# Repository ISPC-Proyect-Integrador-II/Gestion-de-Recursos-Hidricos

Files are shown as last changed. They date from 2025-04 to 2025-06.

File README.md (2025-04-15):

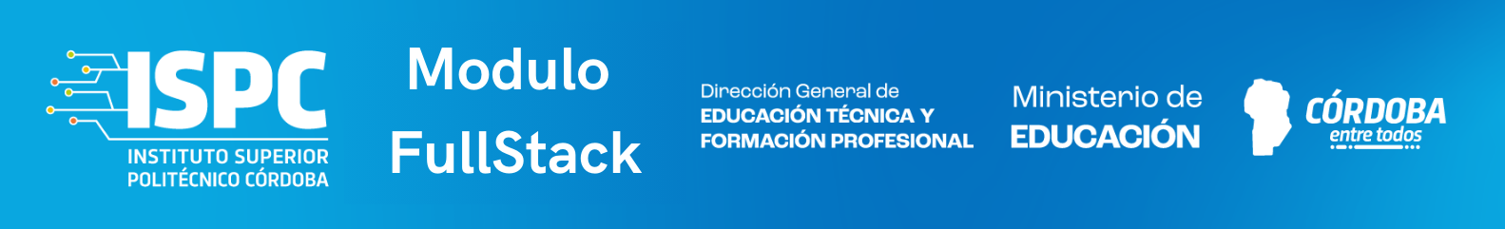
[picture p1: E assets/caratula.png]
Logo de la Institución ISPC


# Módulo Programador FullStack IoT
## Tecnicatura Superior en Telecomunicaciones – Segundo Año

### 🔹 Presentación General  

El módulo Programador FullStack IoT es un espacio interdisciplinario que integra las materias Arquitectura y Conectividad, Sistemas de Control y Servicios y Plataformas, orientado al diseño e implementación de soluciones IoT aplicadas a la industria.
Durante 10 semanas, los estudiantes trabajarán en equipos de 3 a 5 integrantes, desarrollando un proyecto técnico completo que abarque sensado, conectividad, automatización, visualización de datos y documentación profesional.
El trabajo se organiza bajo el enfoque de Aprendizaje Basado en Proyectos (ABP), con metodología Scrum: tres sprints, entregas semanales y seguimiento por parte de los docentes de cada materia. El desarrollo debe gestionarse en GitHub y documentarse en cada etapa.
### 🔹 Selección del Proyecto  

Cada equipo debe elegir un proyecto de base a desarrollar, seleccionando una problemática dentro de una de las siguientes 10 áreas industriales:  

* Gestión Energética

+ Monitoreo Ambiental

+ Trazabilidad de Producción y Logística

+ Mantenimiento Predictivo

+ Seguridad Industrial

+ Monitoreo de Infraestructura

+ Agricultura Inteligente (AgTech)

+ Control de Inventario

+ Gestión de Recursos Hídricos

+ Control de Calidad en Producción

🗂️ Podés acceder a la descripción detallada de cada proyecto en el siguiente enlace:
### 👉 Proyectos para el Módulo PF IoT (PDF) 
🔁 Organización por Sprints
A continuación, se detalla la planificación semanal del módulo, dividida en tres sprints:  

🔁 SPRINT 1  

Exploración y Diseño Conceptual (Semanas 1 a 3)
🎯 Objetivo: Identificar la problemática industrial, investigar, seleccionar tecnologías y diseñar la arquitectura del sistema.
Conformación de equipos y análisis de áreas.

Benchmarking tecnológico y definición del problema.

Selección de sensores, actuadores y protocolos.

Diseño preliminar de red IoT y lógica de control.

Creación del repositorio en GitHub.

Primeros diagramas de arquitectura y flujo.

🔁 SPRINT 2  

Desarrollo e Integración Técnica (Semanas 4 a 7)
🎯 Objetivo: Desarrollar el sistema, integrar sensores, lógica de control y plataforma IoT.
Conexión de sensores físicos o virtuales.

Implementación de lógica de automatización.

Ingesta de datos y visualización inicial en dashboard.

Pruebas funcionales del sistema integrado.

Validación técnica y mejoras sobre el prototipo.

🔁 SPRINT 3  

Optimización y Presentación Final (Semanas 8 a 10)
🎯 Objetivo: Optimizar el sistema, completar la documentación técnica y presentar el proyecto final.
Ajustes técnicos y mejoras visuales.

Finalización de la documentación por materias.

Validación cruzada entre equipos (testing).

Ensayo y presentación final.

Autoevaluación y coevaluación.

### 🎯 Entregable final (Semana 10)  

**Prototipo funcional (simulado o físico)**

**Dashboard operativo**

**Documentación técnica completa**

**Repositorio Git con historial del trabajo**

**Exposición y defensa del proyecto en equipo**

### Profesor
- Cristian Gonzalo Vera | https://github.com/Gona79

### Miembros:
- Luciano Lujan | GitHub: https://github.com/lucianoilujan
- Joaquin Garzón | GitHub: https://github.com/Joacogarzonn
- Durigutti, Vittorio | GitHub: https://github.com/vittoriodurigutti
- Joaquin Zalazar | GitHub: https://github.com/breaakerr
- Lisandro Juncos | GitHub: https://github.com/Lisandro-05
- Nahuel Velez | GitHub: https://github.com/ISPC-TST-PI-I-2024/ISPC_PI_Lucas_Nahuel_Velez 
- Jose Marquez | GitHub: https://github.com/ISPC-TST-PI-I-2024/josemarquez.git
- Maria Lilen Guzmán | GitHub: https://github.com/lilenguzman01
### Índice

### Estructura del Repositorio

- **A requisitos**: Contiene documentos de requisitos proporcionados por el docente.
- **B investigacion**: Investigaciones realizadas por los estudiantes.
- **C prototipo**: Implementaciones específicas de la capa de almacenamiento.
- **D presentacion**: Incluye grabaciones y bitácoras de las reuniones de Scrum, así como las presentaciones de progreso.
- **zassets**: Contiene recursos gráficos como imágenes y otros archivos necesarios para la documentación.

## Stack Tecnológico Común

- Control de Versiones: **Git y GitHub**
- Metodologías Ágiles: **Scrum y Kanban**
- Aprendizaje Basado en Proyectos (ABP)
- Soporte DevOps por parte del docente

## Stack Tecnológico para el Sprint Actual

- IDE: **Visual Studio Code**
- Simulador: **Wokwi o similar**

## Licencia

Este proyecto está licenciado bajo la Licencia Creative Commons Atribución-NoComercial (CC BY-NC). Esta licencia permite que otros remixen, adapten y construyan sobre el trabajo de forma no comercial y, aunque sus nuevos trabajos deben también reconocer al autor original y ser no comerciales, no tienen que licenciar sus obras derivadas en los mismos términos.

Esta licencia es adecuada para un uso educativo y de aprendizaje, permitiendo la libre distribución y utilización del material mientras se protege contra el uso comercial sin autorización previa. Para usos comerciales, es necesario contactar a los autores para obtener permiso.

Para obtener más información sobre esta licencia y ver una copia completa de sus términos, visite [Creative Commons Atribución-NoComercial (CC BY-NC)](https://creativecommons.org/licenses/by-nc/4.0/).

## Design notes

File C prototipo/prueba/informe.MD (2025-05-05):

# Informe Global del Proyecto: Hidroponia Inteligente

El proyecto **Hidroponia Inteligente** está diseñado para monitorear y controlar sistemas hidropónicos usando un ESP32. Su arquitectura modular permite una integración flexible de diversos sensores (temperatura, humedad, pH, nivel de agua, flujo, LDR, gas, INA219) y sistemas de comunicación (WiFi+MQTT, BLE Mesh, LoRa Mesh). Adicionalmente, el sistema incorpora un menú interactivo basado en una pantalla TFT para la selección de opciones y recetas de cultivo, así como un módulo RTC para sincronización de fecha y hora. El sistema admite la operación en modo transmisor o receptor para adaptarse a diferentes arquitecturas de red.

## Características Principales

- **Sensores**: Lectura de información ambiental, de agua, flujo y pH.  
- **Control Automático**: Automatización de riego, iluminación (relé para luces) y alertas basadas en umbrales de seguridad.  
- **Comunicación**:  
  - **WiFi y MQTT**: Conexión remota para enviar y recibir datos.  
  - **BLE Mesh**: Comunicación local entre nodos vía Bluetooth.  
  - **LoRa Mesh**: Comunicación a larga distancia ideal para áreas remotas.
- **RTC**: Módulo de reloj (DS1307/DS3231) para gestionar hora y fecha, permitiendo sincronización y programación de eventos.  
- **Recetas de Cultivo**: Permite guardar y aplicar parámetros óptimos para diferentes cultivos (por ejemplo, lechuga, tomate, albahaca).  
- **Menú Interactivo**: Basado en una pantalla TFT que habilita la navegación entre diferentes opciones: sensores, control, recetas, WiFi, entre otros.  
- **Modos de Operación**:  
  - **Transmisor**: Nodo que recopila y envía datos.  
  - **Receptor**: Nodo que recibe datos y ejecuta acciones basadas en comandos recibidos.

## Arquitectura y Escalabilidad

La estructura modular del código permite realizar ampliaciones y modificaciones sin afectar el funcionamiento global. Cada funcionalidad se encuentra separada en módulos, lo que hace al sistema escalable y de fácil mantenimiento. Además, la integración de múltiples protocolos de comunicación garantiza robustez y adaptabilidad al entorno en que se implemente.

---

# Informe por Carpeta del Proyecto Hidroponia

A continuación, se detalla qué encontrarás en cada carpeta y los archivos asociados, junto con una breve descripción de su función.

## 1. **Raíz del Proyecto**

- **Hidroponia.ino**  
  Archivo principal donde se integran y utilizan todos los módulos. Aquí se define el ciclo de trabajo (setup y loop) que gestiona la inicialización de los distintos módulos, la lectura periódica de sensores, y la gestión de comunicaciones y menús.

- **Configuración.h**  
  Contiene definiciones básicas para la configuración global del sistema (por ejemplo, velocidad de comunicación, versión del firmware, constantes generales).

- **Configuración_avanzada.h**  
  Aquí se establecen parámetros más finos y de calibración, como constantes para calibrar el sensor de pH o la temperatura. Permite ajustar valores sin modificar el código base en otros módulos.

## 2. **src/sensores**

Contiene todo lo relacionado con la lectura y gestión de los sensores.

- **sensores.h / sensores.cpp**  
  Funciones para inicializar y leer datos de varios sensores: DHT11 (temperatura y humedad ambiente), DS18B20 (temperatura del agua), sensor ultrasónico (nivel de agua), caudalímetro (flujo de agua), LDR (luz ambiente), MQ7 (sensor de gas) e INA219 (corriente, voltaje y potencia).

- **ph_sensor.h / ph_sensor.cpp**  
  Código específico para la lectura del sensor de pH. Incluye declaraciones para inicializar el sensor y leer el valor de pH, utilizando una conversión lineal básica que se puede calibrar según las características del sensor.

## 3. **src/control**

Contiene la lógica de control y automatización del sistema.

- **control.h / control.cpp**  
  Módulo que define los umbrales para cada sensor (por ejemplo, rangos de temperatura, humedad, nivel de agua) y gestiona la activación/desactivación de dispositivos (como la bomba de agua) según los datos obtenidos. Incluye funciones para verificar alarmas, automatizar riego y notificar estados.

- **iluminacion.h / iluminacion.cpp**  
  Maneja el control de un relé destinado a la iluminación artificial. Permite inicializar el relé y cambiar su estado (encendido/apagado) para complementar la entrada natural de luz.

## 4. **src/pantalla**

Módulo responsable de la interfaz visual y los menús interactivos.

- **pantalla.h / pantalla.cpp**  
  Código de inicialización y manejo de la pantalla TFT, utilizando la librería Adafruit GFX y ST7735. Se incluyen funciones para animaciones (por ejemplo, modo standby con parpadeo de "ojos") y para actualizar la pantalla según el estado del sistema.

- **menu.h / menu.cpp**  
  Funciones para presentar el Menú Principal. Permite navegar entre las diferentes opciones de configuración del sistema (sensores, control, recetas, WiFi).

- **menu_recetas.h / menu_recetas.cpp**  
  Módulo dedicado al manejo y selección de recetas de cultivo. Permite visualizar y seleccionar recetas predefinidas almacenadas en EEPROM para ajustar parámetros óptimos para diferentes cultivos.

- **menu_wifi.h / menu_wifi.cpp**  
  Proporciona una interfaz para el escaneo y selección de redes WiFi disponibles. Permite al usuario elegir una red y guardar la configuración para conexiones futuras.

## 5. **src/comunicacion**

Contiene todos los módulos relacionados con la comunicación, tanto para la conexión remota como para la comunicación en malla.

- **comunicacion.h / comunicacion.cpp**  
  Módulo central que integra las funciones de comunicación: conexión a WiFi, MQTT, y llamadas a funciones de otros módulos (como BLE y LoRa). Se manejan reconexiones y la publicación de datos (por ejemplo, alertas o datos de sensores).

- **wifi_manager.h / wifi_manager.cpp**  
  Funciones para la gestión del WiFi: escaneo de redes, conexión y almacenamiento de credenciales en EEPROM para que el dispositivo se conecte automáticamente a la red configurada.

- **ble_mesh.h / ble_mesh.cpp**  
  Módulo para la comunicación BLE Mesh. Inicia el servidor BLE, define servicios y características para transmitir y recibir mensajes en la red de malla Bluetooth.

- **lora_mesh.h / lora_mesh.cpp**  
  Módulo para la comunicación LoRa Mesh. Configura el módulo LoRa (por ejemplo, el SX1278) para enviar y recibir mensajes en largas distancias en frecuencias específicas.

- **transmisor.h / transmisor.cpp**  
  Define el modo de operación para el nodo transmisor. Incluye funciones para enviar datos (por ejemplo, en formato JSON) a través de MQTT y otras redes, basándose en la lectura de sensores.

- **receptor.h / receptor.cpp**  
  Define el modo de operación para el nodo receptor. Procesa los mensajes entrantes y ejecuta acciones (por ejemplo, activar la iluminación) según comandos específicos recibidos.

## 6. **src/rtc**

Módulo para el manejo del reloj real (RTC).

- **rtc.h / rtc.cpp**  
  Código para inicializar y sincronizar el RTC (como DS1307 o DS3231). Se incluyen funciones para obtener la fecha y hora actual, y para ajustar el reloj a partir de datos externos (por ejemplo, mediante MQTT).

## 7. **src/recetas**

Módulo para la gestión de recetas de cultivo, que permiten guardar parámetros específicos para diferentes plantas.

- **recetas.h / recetas.cpp**  
  Define una estructura llamada `Receta` que guarda parámetros como temperatura del agua, temperatura ambiente, humedad, nivel de agua, pH e información sobre iluminación. Permite cargar y guardar recetas en la EEPROM, seleccionar una receta y mostrar sus parámetros.

## 8. **bibliotecas**

Esta carpeta contendrá las librerías externas que debes instalar (aunque muchas se descargan automáticamente desde el gestor de librerías de Arduino o PlatformIO). Aquí se pueden incluir, por ejemplo:  
- Adafruit_GFX, Adafruit_ST7735  
- PubSubClient  
- LoRa  
- BLEDevice  
- RTClib  
- EEPROM (ya incluida en Arduino)  

## 9. **Errores y manejo de informacion**

- **errores.h / errores.cpp** 

En la carpeta se encuetra el catagolo de categoria y mensaje por indexacion de los posibles errores en diferentes funciones del sistema, Y la funcion encargada de la gestion y producccion de los mensajes

Se adjunta documento **errores.md** con el catagolo en formato de lectura para facilitar acceso a los posibles errores contemplados
---

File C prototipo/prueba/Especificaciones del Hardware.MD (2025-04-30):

# 🛠️ **Especificaciones del Hardware: Hidroponia Inteligente en ESP32**  

## 📌 **1. Microcontrolador Principal: ESP32**  
El sistema está basado en el **ESP32**, un microcontrolador con conectividad WiFi y Bluetooth, múltiples entradas analógicas/digitales y capacidad de procesamiento eficiente para proyectos IoT y automatización.

### **🔹 Características Clave del ESP32:**  
✔ 240 MHz de frecuencia de CPU.  
✔ 520 KB de SRAM.  
✔ WiFi integrado para conexión remota.  
✔ Bluetooth BLE para comunicación de corto alcance.  
✔ Múltiples puertos ADC y PWM para sensores y actuadores.  
✔ Bajo consumo energético para funcionamiento eficiente.  

### **🔹 Conexión del ESP32:**  
✔ **Alimentación:** Se puede alimentar con **5V desde un adaptador USB** o con una **batería externa**.  
✔ **Pines digitales:** Se usan para controlar el relé de la bomba y la iluminación.  
✔ **Pines analógicos:** Se usan para sensores como pH, flujo y nivel de agua.  

---

## 📌 **2. Sensores Integrados en el Sistema**  

El sistema cuenta con varios sensores para monitoreo en tiempo real:  

### **🔹 Sensor de Temperatura y Humedad (DHT11 / DHT22)**  
✔ Conectado a un **pin digital** del ESP32.  
✔ Mide temperatura y humedad ambiente.  

### **🔹 Sensor de Temperatura del Agua (DS18B20)**  
✔ Conectado mediante **OneWire** a un pin del ESP32.  
✔ Mide la temperatura del agua para optimizar el cultivo.  

### **🔹 Sensor de Nivel de Agua (Ultrasónico HC-SR04)**  
✔ Utiliza **dos pines digitales**: `Trigger` y `Echo`.  
✔ Mide la distancia hasta la superficie del agua.  

### **🔹 Sensor de Flujo de Agua (Caudalímetro YF-S201)**  
✔ Conectado a un **pin de interrupción** del ESP32.  
✔ Mide el flujo de agua en litros por minuto.  

### **🔹 Sensor de pH (Electrodo + Amplificador PH-4502C)**  
✔ Conectado a un **pin analógico** del ESP32.  
✔ Proporciona medición del pH del agua en tiempo real.  

### **🔹 Sensor de Luz (LDR)**  
✔ Conectado a un **pin analógico**.  
✔ Detecta la cantidad de luz ambiental para activar la iluminación artificial.  

### **🔹 Sensor de Gas (MQ7)**  
✔ Conectado a un **pin analógico**.  
✔ Detecta concentraciones de gases que puedan afectar el cultivo.  

### **🔹 Sensor de Corriente y Voltaje (INA219)**  
✔ Conectado vía **I2C** para medir corriente y voltaje en el sistema.  
✔ Permite monitorear el consumo de energía del sistema hidropónico.  

---

## 📌 **3. Actuadores del Sistema**  

El sistema controla dispositivos físicos a través de relés y bombas:  

### **🔹 Relé para la Bomba de Agua**  
✔ Conectado a un **pin digital** del ESP32.  
✔ Activa o desactiva el bombeo según el nivel de agua.  

### **🔹 Relé para la Iluminación Artificial**  
✔ Conectado a un **pin digital** del ESP32.  
✔ Enciende o apaga luces LED para mejorar el crecimiento de las plantas.  

---

## 📌 **4. Módulos de Comunicación**  

### **🔹 Conexión WiFi + MQTT**  
✔ Se configura en `wifi_manager.h` y `comunicacion.h`.  
✔ Permite enviar datos a servidores remotos y recibir comandos.  

### **🔹 BLE Mesh (Bluetooth de corto alcance entre nodos)**  
✔ Configurado en `ble_mesh.h` y `ble_mesh.cpp`.  
✔ Permite comunicación entre múltiples ESP32 sin requerir WiFi.  

### **🔹 LoRa Mesh (Comunicación de larga distancia sin WiFi)**  
✔ Se configura en `lora_mesh.h` y `lora_mesh.cpp`.  
✔ Permite enviar datos a largas distancias en entornos sin Internet.  

---

## 📌 **5. Diagrama de Conexión**  

```
ESP32
 ├── Sensores:
 │   ├── DHT11 (Temp/Humedad) → Pin Digital
 │   ├── DS18B20 (Temp Agua) → Pin OneWire
 │   ├── HC-SR04 (Nivel Agua) → Pines Trigger/Echo
 │   ├── YF-S201 (Flujo Agua) → Pin de interrupción
 │   ├── PH-4502C (Sensor pH) → Pin Analógico
 │   ├── LDR (Sensor de Luz) → Pin Analógico
 │   ├── MQ7 (Sensor de Gas) → Pin Analógico
 │   ├── INA219 (Corriente/Voltaje) → I2C
 ├── Actuadores:
 │   ├── Relé Bomba Agua → Pin Digital
 │   ├── Relé Iluminación → Pin Digital
 ├── Comunicación:
 │   ├── WiFi (MQTT) → `wifi_manager.h`
 │   ├── BLE Mesh → `ble_mesh.h`
 │   ├── LoRa Mesh → `lora_mesh.h`
```

---

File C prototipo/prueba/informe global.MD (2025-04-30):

# Informe Global del Proyecto: Hidroponia Inteligente para ESP32

El proyecto **Hidroponia Inteligente** está desarrollado sobre un ESP32 y está orientado a monitorear y controlar un sistema hidropónico de forma remota e inteligente. La arquitectura es modular, lo que permite integrar múltiples sensores, gestionar la automatización y establecer comunicación de diversas formas (WiFi + MQTT, BLE Mesh y LoRa Mesh).

## Características Principales

- **Sensores y Medidas**  
  - *Sensores ambientales*: Temperatura y humedad (DHT11).  
  - *Sensor de agua*: Temperatura (DS18B20), nivel (ultrasónico) y flujo (caudalímetro).  
  - *Medición adicional*: Sensor de pH (con conversión básica que se puede calibrar).  
  - *Otros*: Sensor de luz (LDR), sensor de gas (MQ7) y monitorización de corriente/voltaje (INA219).

- **Control y Automatización**  
  - Gestión de riego y control de bomba.
  - Control de iluminación artificial mediante un relé.
  - Verificación de alarmas y notificaciones vía MQTT.
  - Automatización adaptativa a partir de umbrales configurables (definidos en el módulo de control).

- **Comunicaciones y Redes**  
  - **WiFi y MQTT:** El ESP32 se conecta a una red WiFi y publica datos en un broker MQTT.  
  - **BLE Mesh:** Operación en red de malla a corto alcance mediante BLE.  
  - **LoRa Mesh:** Comunicación a largas distancias en redes remotas.  
  - **Modos de Operación:** Se puede configurar el nodo en modo transmisor (envía datos) o receptor (procesa y ejecuta comandos recibidos).

- **Interfaz Visual y Menús**  
  - Uso de una pantalla TFT (con Adafruit_GFX y ST7735) para mostrar información, menús interactivos y animaciones (modo standby, alertas, etc.).  
  - Menús para la configuración general, selección de recetas de cultivo y de red WiFi.

- **Recetas de Cultivo y Configuración**  
  - Almacenamiento en EEPROM de recetas con parámetros óptimos para diferentes cultivos (p.ej. lechuga, tomate, albahaca).  
  - Parámetros ajustables y calibración fina a través de archivos de configuración.

- **Sincronización Horaria (RTC)**  
  - Integración de módulos RTC (DS1307/DS3231) para mantener la hora correcta, programar eventos y registrar datos con marca temporal.

## Ventajas y Escalabilidad

- **Modularidad:** Cada funcionalidad se encuentra en su propio módulo, lo que facilita la ampliación o modificación sin afectar el sistema global.
- **Flexibilidad:** Los nodos se pueden configurar como transmisores o receptores, permitiendo distintas arquitecturas de red para distribuir las tareas.
- **Robustez:** Los diferentes canales de comunicación (WiFi, BLE, LoRa) y el almacenamiento local (EEPROM) garantizan persistencia y adaptabilidad a diversas condiciones de red y energía.
- **Diseñado para ESP32:** Aprovecha la capacidad de procesamiento, conectividad WiFi/BLE y las múltiples interfaces analógicas/digitales que posee este microcontrolador.

---

# Informe por Carpeta del Proyecto

A continuación se describe en detalle la estructura del proyecto y los archivos que encontrarás en cada carpeta, junto con una breve descripción de sus responsabilidades.

## Raíz del Proyecto

- **Hidroponia.ino**  
  Es el archivo principal que integra todos los módulos. En él se define el ciclo de trabajo (`setup()` y `loop()`), donde se inicializan la pantalla, sensores, control, comunicaciones y menús, y se coordina la lectura y envío de datos periódicamente.

- **Configuración.h**  
  Contiene definiciones y constantes globales (p.ej. velocidad de comunicación, versión del firmware) que se usan en varias partes del proyecto.

- **Configuración_avanzada.h**  
  Se establecen parámetros finos de calibración y ajustes avanzados (por ejemplo, constantes de calibración para el sensor de pH o parámetros de referencia para otros sensores).

## Carpeta `src/sensores`

- **sensores.h / sensores.cpp**  
  Funcionalidad común para la lectura y manejo de sensores:
  - Inicializa y lee datos de DHT11, DS18B20, sensor ultrasónico, caudalímetro, LDR, MQ7 y INA219.
  - Proporciona variables globales para almacenar los valores medidos (temperatura del agua, temperatura ambiente, nivel de agua, flujo, etc.).

- **ph_sensor.h / ph_sensor.cpp**  
  Específico para el sensor de pH:
  - Se encarga de inicializar el sensor y realizar la conversión analógica a un valor de pH, utilizando una fórmula básica que puede ser ajustada posteriormente.

## Carpeta `src/control`

- **control.h / control.cpp**  
  Define la lógica de control:
  - Establece umbrales para activar la bomba, gestionar riego y otros dispositivos.
  - Incluye funciones para verificar alarmas basadas en las lecturas de los sensores y notificar eventos especiales (por ejemplo, baja del nivel de agua o pH fuera de rango).

- **iluminacion.h / iluminacion.cpp**  
  Maneja el control de un relé destinado a la iluminación artificial:
  - Se definen funciones para inicializar el relé y cambiar su estado (encendido/apagado) dependiendo de las condiciones ambientales o configuraciones manuales.

## Carpeta `src/pantalla`

- **pantalla.h / pantalla.cpp**  
  Encargado de la interfaz visual:
  - Inicializa la pantalla TFT y define funciones para actualizarla, mostrar animaciones (modo standby o alertas) y renderizar información en pantalla.

- **menu.h / menu.cpp**  
  Proporciona el menú principal del sistema:
  - Maneja la navegación del usuario para acceder a distintos apartados (sensores, control, recetas y configuración WiFi).
  
- **menu_recetas.h / menu_recetas.cpp**  
  Gestión del menú de recetas de cultivo:
  - Permite la visualización, selección y edición de recetas almacenadas en EEPROM para ajustar parámetros de cultivo.
  
- **menu_wifi.h / menu_wifi.cpp**  
  Funcionalidades para la selección de red WiFi:
  - Escanea las redes disponibles, muestra una lista en la pantalla y permite al usuario seleccionar la red a la que conectar el ESP32.

## Carpeta `src/comunicacion`

- **comunicacion.h / comunicacion.cpp**  
  Módulo central para la gestión de comunicaciones:
  - Integra funciones para conectarse a WiFi, a un broker MQTT y para manejar la publicación y suscripción de mensajes.
  
- **wifi_manager.h / wifi_manager.cpp**  
  Gestión de las conexiones WiFi:
  - Escanea redes WiFi, conecta al canal seleccionado y guarda los datos en EEPROM para la reconexión automática.
  
- **ble_mesh.h / ble_mesh.cpp**  
  Módulo para la comunicación mediante BLE Mesh:
  - Configura un servidor BLE en el ESP32, define servicios y características para transmitir mensajes por Bluetooth en una red de malla.
  
- **lora_mesh.h / lora_mesh.cpp**  
  Módulo para la comunicación a larga distancia vía LoRa:
  - Configura el módulo LoRa (por ejemplo, SX1278) con los pines y frecuencia adecuados, y gestiona el envío y recepción de mensajes.
  
- **transmisor.h / transmisor.cpp**  
  Define el modo transmisor:
  - Recopila datos de los sensores y los envía (por ejemplo, vía MQTT). Se habilita o deshabilita mediante una variable (esNodoTransmisor).
  
- **receptor.h / receptor.cpp**  
  Define el modo receptor:
  - Procesa los mensajes recibidos (por ejemplo, comandos para activar iluminación o ajustar parámetros) y ejecuta acciones en consecuencia.

## Carpeta `src/rtc`

- **rtc.h / rtc.cpp**  
  Módulo para la gestión del reloj real (RTC):
  - Inicializa el RTC, obtiene la fecha y hora actual y permite sincronizar el reloj (por ejemplo, mediante mensajes recibidos por MQTT).

## Carpeta `src/recetas`

- **recetas.h / recetas.cpp**  
  Gestión de recetas de cultivo:
  - Define la estructura `Receta` que almacena parámetros como temperatura, humedad, nivel de agua, pH e iluminación.
  - Permite cargar y guardar estas recetas en EEPROM, seleccionar una receta y mostrar sus parámetros en el sistema.

## Carpeta `bibliotecas`

- **Librerías Externas**  
  Esta carpeta se utiliza para almacenar (o referenciar) las librerías externas requeridas, tales como:
  - Adafruit_GFX, Adafruit_ST7735 (para la pantalla TFT).  
  - PubSubClient (para MQTT).  
  - LoRa, BLEDevice, RTClib y EEPROM (incluida en Arduino).  
  La mayoría de estas librerías se instalan a través del gestor de librerías de Arduino o PlatformIO.

---

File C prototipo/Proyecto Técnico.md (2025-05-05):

# 🌱 Sistema Hidropónico Automatizado con ESP32

## 🧠 Microcontrolador
- **Placa principal:** NodeMCU ESP32 WROOM (38 pines)
- **Tensión de operación:** 3.3V
- **Tensión de alimentación:** 5V vía USB
- **Comunicación:** Wi-Fi, Bluetooth, UART, SPI, I2C

## 📌 Mapeo Completo de Pines ESP32 (NodeMCU ESP32 WROOM)

| Pin | GPIO | Nombre | Estado | Uso en Proyecto |
|-----|---|---|---|---|
| 1 | - | 3V3 | Ocupado | Alimentación para sensores de 3.3V |
| 2 | GPIO23 | IO23 | Ocupado | LoRa MOSI |
| 3 | GPIO22 | IO22/SCL | Ocupado | I2C SCL (INA219, RTC DS1307) |
| 4 | GPIO1 | TX | Libre | - |
| 5 | GPIO3 | RX | Libre | - |
| 6 | GPIO21 | IO21/SDA | Ocupado | I2C SDA (INA219, RTC DS1307) |
| 7 | GND | GND | Ocupado | Tierra común |
| 8 | GPIO19 | IO19 | Ocupado | LoRa MISO |
| 9 | GPIO18 | IO18 | Ocupado | LoRa SCK |
| 10 | GPIO5 | IO5 | Ocupado | LoRa NSS |
| 11 | GPIO17 | IO17 | Ocupado | SIM800L TX |
| 12 | GPIO16 | IO16 | Ocupado | SIM800L RX |
| 13 | GPIO4 | IO4 | Libre | - |
| 14 | GPIO0 | IO0 | Ocupado | Display TFT RESET |
| 15 | GPIO2 | IO2 | Libre | - |
| 16 | GPIO15 | IO15 | Ocupado | LoRa RST |
| 17 | GPIO13 | IO13 | Ocupado | Display TFT CS |
| 18 | GPIO12 | IO12 | Ocupado | Display TFT DC, HC-SR04 TRIG |
| 19 | GPIO14 | IO14 | Ocupado | Display TFT MOSI |
| 20 | GPIO27 | IO27 | Ocupado | Display TFT SCK, Buzzer Pasivo |
| 21 | GPIO26 | IO26 | Ocupado | Bomba Sumergible (Relay 1 Canal) |
| 22 | GPIO25 | IO25 | Ocupado | DHT11/DHT22 DATA |
| 23 | GPIO33 | IO33 | Ocupado | DS18B20 DATA |
| 24 | GPIO32 | IO32 | Ocupado | HC-SR04 ECHO |
| 25 | GPIO35 | IO35 | Ocupado | Relay 2 Canal |
| 26 | GPIO34 | IO34 | Ocupado | LoRa DIO0 |
| 27 | GPIO39 | IO39/VN | Ocupado | Sensor LDR, Medidor de pH |
| 28 | GPIO36 | IO36/VP | Ocupado | Sensor MQ-7 |
| 29 | EN | EN | Sistema | - |
| 30 | - | 5V | Ocupado | Alimentación para sensores de 5V |

## 📌 Distribución de Pines para Sensores

| Sensor / Módulo | Tipo de conexión | Pines ESP32 |
|---|---|---|
| **Bomba Sumergible (Relay)** | Digital | GPIO 26 |
| **Buzzer Pasivo** | PWM / Digital | GPIO 27 |
| **Caudalímetro** | Pulso digital | GPIO 32 |
| **Sensor de Corriente INA219** | I2C | SDA = GPIO 21, SCL = GPIO 22 |
| **RTC DS1307 + EEPROM AT24C32** | I2C | SDA = GPIO 21, SCL = GPIO 22 |
| **Sensor de Temperatura DS18B20** | 1-Wire | GPIO 33 |
| **Sensor de Gas MQ7** | Analógico | GPIO 36 (VP) |
| **Display TFT ST7735 (SPI)** | SPI | CS = GPIO 13, DC = GPIO 12, RESET = GPIO 0, MOSI = GPIO 14, SCK = GPIO 27 |
| **Sensor DHT11/DHT22** | Digital | GPIO 25 |
| **Sensor de Luz LDR** | Analógico | GPIO 39 (VN) |
| **Sensor Ultrasonido HC-SR04** | Digital | TRIG = GPIO 12, ECHO = GPIO 32 |
| **Módulo GSM SIM800L** | UART | RX = GPIO 16, TX = GPIO 17 |
| **Módulo LoRa SX1278 (SPI)** | SPI | NSS = GPIO 5, MOSI = GPIO 23, MISO = GPIO 19, SCK = GPIO 18, RST = GPIO 15, DIO0 = GPIO 34 |
| **Relay 1 Canal** | Digital | GPIO 26 |
| **Relay 2 Canal** | Digital | GPIO 35 |
| **Medidor de pH** | ADC | GPIO 39 (ADC1_CH3) |

## 🔌 Conexiones de Módulos y Sensores

### 1. **Bomba Sumergible + Relay**
- **Relay VCC** → 5V
- **Relay GND** → GND
- **Relay IN** → GPIO 26
- **COM (Relay)** → + de la bomba
- **NO (Relay)** → + de fuente de 5V externa
- **Bomba GND** → GND fuente

---

### 2. **Buzzer Pasivo**
- **VCC** → 5V
- **GND** → GND
- **Señal** → GPIO 27

---

### 3. **Caudalímetro**
- **VCC** → 5V
- **GND** → GND
- **Señal (pulso)** → GPIO 32

---

### 4. **Sensor de Corriente INA219**
- **VCC** → 3.3V
- **GND** → GND
- **SDA** → GPIO 21
- **SCL** → GPIO 22

---

### 5. **RTC DS1307 + EEPROM**
- **VCC** → 3.3V o 5V
- **GND** → GND
- **SDA** → GPIO 21
- **SCL** → GPIO 22

---

### 6. **Sensor DS18B20**
- **VCC** → 3.3V
- **GND** → GND
- **DATA** → GPIO 33
- **Resistencia** (pull-up 4.7kΩ entre DATA y VCC)

---

### 7. **Sensor MQ-7 (CO)**
- **VCC** → 5V
- **GND** → GND
- **AOUT** → GPIO 36

---

### 8. **Display TFT ST7735**
- **VCC** → 3.3V
- **GND** → GND
- **CS** → GPIO 13
- **RESET** → GPIO 0
- **DC** → GPIO 12
- **MOSI** → GPIO 14
- **SCK** → GPIO 27

---

### 9. **Sensor DHT11/DHT22**
- **VCC** → 3.3V
- **GND** → GND
- **DATA** → GPIO 25

---

### 10. **Sensor de Luz (LDR)**
- Un extremo del **LDR** → 3.3V
- Otro extremo → resistencia de 10kΩ a GND y punto medio al GPIO 39

---

### 11. **HC-SR04**
- **VCC** → 5V
- **GND** → GND
- **TRIG** → GPIO 12
- **ECHO** → GPIO 32 *(usar divisor de voltaje para 3.3V)*

---

### 12. **SIM800L (Módulo GSM)**
- **VCC** → Fuente externa 4V
- **GND** → GND común
- **TX (SIM800L)** → GPIO 16 (RX ESP32)
- **RX (SIM800L)** → GPIO 17 (TX ESP32) *(usar 3.3V)*

---

### 13. **LoRa SX1278**
- **VCC** → 3.3V
- **GND** → GND
- **MOSI** → GPIO 23
- **MISO** → GPIO 19
- **SCK** → GPIO 18
- **NSS (CS)** → GPIO 5
- **RESET** → GPIO 15
- **DIO0** → GPIO 34

---

### 14. **Medidor de pH**
- **VCC** → 5V
- **GND** → GND
- **Salida Analógica** → GPIO 39 *(ADC1_CH3)*

---

## 📋 Lista de Materiales

| Componente | Cantidad | Descripción |
|---|---|---|
| NodeMCU ESP32 WROOM | 1 | Microcontrolador con WiFi y Bluetooth (38 pines) |
| Relay 1 Canal | 1 | Para control de bomba sumergible |
| Relay 2 Canal | 1 | Para control de actuadores adicionales |
| Buzzer Pasivo | 1 | Para alertas sonoras |
| Caudalímetro | 1 | Sensor de flujo de agua (0.3-6 L/min) |
| INA219 | 1 | Sensor de corriente de alta precisión |
| DS1307 + AT24C32 | 1 | Reloj de tiempo real con EEPROM |
| DS18B20 | 1 | Sensor de temperatura resistente al agua |
| MQ-7 | 1 | Sensor de monóxido de carbono |
| Display TFT ST7735 | 1 | Pantalla a color SPI 1.8" |
| DHT11/DHT22 | 1 | Sensor de temperatura y humedad |
| LDR | 1 | Fotorresistor para medir intensidad de luz |
| HC-SR04 | 1 | Sensor ultrasónico de distancia |
| SIM800L | 1 | Módulo GSM para comunicación celular |
| LoRa SX1278 | 1 | Módulo de comunicación de largo alcance |
| Sensor de pH | 1 | Medidor del pH del agua |
| Bomba Sumergible | 1 | Bomba de agua para circulación |
| Resistencias | Varias | 10kΩ (para LDR), 4.7kΩ (para DS18B20), divisor de voltaje |
| Cables Dupont | Varios | Para interconexión de componentes |
| Protoboard | 1 | Para montaje de circuito |
| Fuente de alimentación | 1 | 5V/2A para ESP32 y 4V para SIM800L |

## 🔄 Tipos de Conexiones

### I2C (Inter-Integrated Circuit) – Bus compartido
Todos los módulos que usan I2C están en el mismo bus para reducir consumo y mejorar estabilidad:
| Sensor / Módulo | Dirección I2C | Pines ESP32 |
|---|---|---|
| Sensor de Corriente INA219 | 0x40 | SDA = GPIO 21, SCL = GPIO 22 |
| RTC DS1307 + EEPROM AT24C32 | 0x68 / 0x57 | SDA = GPIO 21, SCL = GPIO 22 |

### SPI (Serial Peripheral Interface) – Bus compartido
Para mejorar eficiencia, algunos dispositivos comparten el bus SPI con pines CS independientes:
| Sensor / Módulo | Pines ESP32 |
|---|---|
| Display TFT ST7735 | MOSI = GPIO 14, SCK = GPIO 27, CS = GPIO 13 |
| Módulo LoRa SX1278 | MOSI = GPIO 23, MISO = GPIO 19, SCK = GPIO 18, CS = GPIO 5 |

### Entradas Analógicas
El ESP32 cuenta con ADC (convertidor analógico a digital) en varios pines:
| Sensor / Módulo | Canal ADC | Pines ESP32 |
|---|---|---|
| Sensor LDR | ADC1_CH3 | GPIO 39 (VN) |
| Sensor MQ-7 | ADC1_CH0 | GPIO 36 (VP) |
| Medidor de pH | ADC1_CH3 | GPIO 39 (VN) |

## ⚙️ Funcionalidades del Sistema
✅ Control automático de riego con bomba sumergible  
✅ Medición de caudal con sensor de flujo  
✅ Monitoreo de temperatura ambiental y del agua  
✅ Medición de concentración de CO2  
✅ Visualización en pantalla TFT  
✅ Envío de alertas por SMS vía GSM (SIM800L)  
✅ Sincronización horaria con RTC DS1307  
✅ Nivel de tanque por ultrasonido  
✅ Comunicación remota por radiofrecuencia (LoRa)  
✅ Detección de condiciones de luz (cultivo LED o solar)  
✅ Medición de pH del agua

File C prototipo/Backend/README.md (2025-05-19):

## API 01

### Procesamiento de Informacion y Registro en BD

Esta API funcionara como el nodo conector entre el dispositivo fisico y las Bases de datos
Purgara la informacion, y ordenara, y posteriormente registrara en los formatos adecuador para poder reflejar los datos de manera informativa, y en tiempo real. 
La misma escuchara de forma pasiva los mensajes presnetes en los topicos en que los dispositivos registren sus lecturas, corriendo en un contenedor Docker, conectado a la red donde se desplegaran asi mismo la base de datos en MySQL e InfluxDB.

---

### Estructura del Directorio

- 📦Backend
-  ┣ 📂app                          // Directorio principal de la aplicacion
-  ┃ ┣ 📂api                        // Elementos de inico de la AIP y gestion de routas [host/api]
-  ┃ ┃ ┣ 📜routes.py                // Gestor de rutas definidas en la aplicacion
-  ┃ ┃ ┗ 📜__init__.py              // Elemento importador de los endpoind del directorio 
-  ┃ ┣ 📂models                     // Elementos asociado a modelos predefinidos, de momento solo estructura de los mensajes recividos
-  ┃ ┃ ┗ 📜mensaje.py               // Estructurador de formato de los mensjaes
-  ┃ ┣ 📂services                   // Estructura la conexion con los diferentes servicios a los que conecta la API
-  ┃ ┃ ┣ 📜influx_serv.py           // Estructura conexion con la base de datos en Influx
-  ┃ ┃ ┗ 📜mysql_serv.py            // Estructura conexion con la base de datos en MySQL
-  ┃ ┣ 📂utils
-  ┃ ┃ ┗ 📜logger.py                // Gestiona los logs del sistema, asi como la categorizacion de los mismos
-  ┃ ┣ 📜config.py                  // Configuracion de la aplicacion y sus endpoints. Estps son llamados del .env
-  ┃ ┣ 📜main.py                    // Cuerpo de la aplicacion. Inicio, gestion del listener, del healtcheck, y ruta principal  
-  ┃ ┣ 📜mqtt_listener.py           // Listener en segundo plano de las conexiones y topicos MQTT
-  ┃ ┗ 📜__init__.py
-  ┣ 📜.env                         // Documento de enviroment donde se definen los valores finales antes de desplegar
-  ┣ 📜.gitignore                   
-  ┣ 📜docker-compose.yml           // Docke-compose para creacion y parametros del contenedor
-  ┣ 📜Dockerfile
-  ┣ 📜README.md
-  ┗ 📜requirements.txt             // Librerias/instalaciones que deben ejecutarse en la imagen del contenedor

---

### Instacion solicitadas en el "requirements.txt"
- fastapi
    - Framework web asíncrono sobre el que montamos nuestros endpoints y el ciclo de vida de la app.
- uvicorn[standard]
    - Servidor ASGI ligero para ejecutar FastAPI, con extras ([standard]) como watchdog para recarga en caliente.
- paho-mqtt
    - Cliente MQTT para suscribirte a topics y procesar mensajes.
- mysql-connector-python
    - Driver oficial de Oracle para conectar a MySQL desde Python.
- influxdb-client
    - Cliente oficial para lectura/escritura en InfluxDB 2.x.
- python-dotenv
    - (Opcional si tu editor o entorno no carga .env automáticamente) permite que Pydantic BaseSettings lea tu .env.
- sqlalchemy
    - ORM/kit de conexión SQL que te facilitará abstraer consultas y gestión de sesiones en MySQL.

---

### Flujo de Datos

```mermaid
flowchart LR
  %% Dispositivo que envía mensajes al broker MQTT
  Dispositivo[Dispositivo]

  %% MQTT subsystem
  subgraph MQTT_Listener
    direction TB
    Broker[MQTT Broker]
    Listener["MQTTListener
(on_message)"]
  end

  %% Persistence services
  subgraph Persistence
    direction TB
    MySQLService[MySQL Service]
    InfluxService[InfluxDB Service]
    MySQLDB[(MySQL DB)]
    InfluxDB[(InfluxDB)]
  end

  %% HTTP API
  subgraph HTTP_API
    direction TB
    Client["API Client
(e.g. dashboard)"]
    FastAPI[FastAPI App]
    Router[/api router/]
    Health[/GET /health/]
    Topics[/GET /api/topics/]
    Messages[/GET /api/messages/]
  end

  %% Connections
  Dispositivo --> Broker
  Broker --> Listener
  Listener -->|payload JSON| MySQLService
  Listener -->|payload JSON| InfluxService
  MySQLService --> MySQLDB
  InfluxService --> InfluxDB

  Client --> FastAPI
  FastAPI --> Health
  FastAPI --> Router
  Router --> Topics
  Router --> Messages
  Messages -->|consulta| MySQLService
  Messages -->|consulta| InfluxService

```

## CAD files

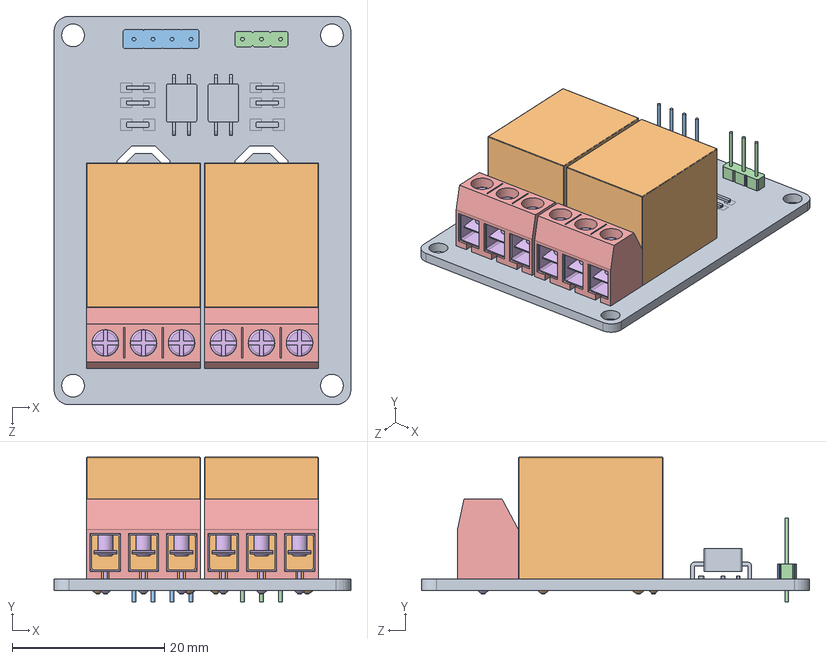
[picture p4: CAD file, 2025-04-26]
C prototipo/Extructura 3D/Archivos editables/Relay - 2 Channel - 2PH63091A - Montaj.SLDASM
39.0 x 19.0 x 51.0 mm
2PH63091A Board
Relay Body x 2
4 Headers
Headers
Clamp Body x 2
Metal Clamp Part x 6

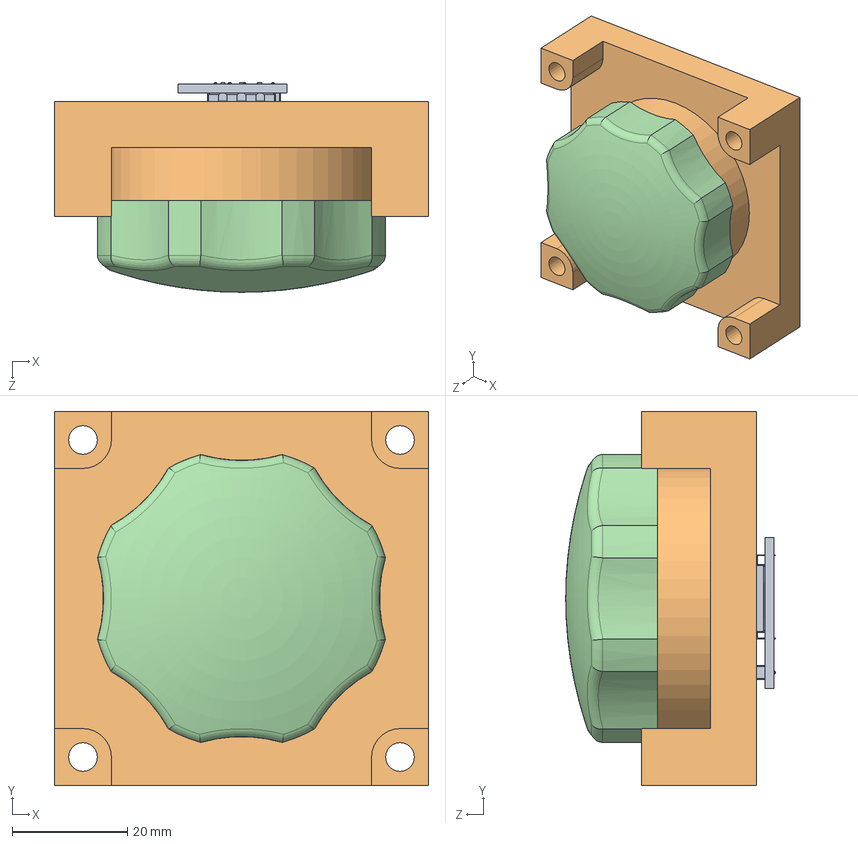
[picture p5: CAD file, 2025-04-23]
C prototipo/Extructura 3D/Archivos editables/perilla.SLDASM
65.0 x 65.0 x 36.4 mm
Rotary Encoder - KY-040
chasis_perilla
rodamiento
perilla52

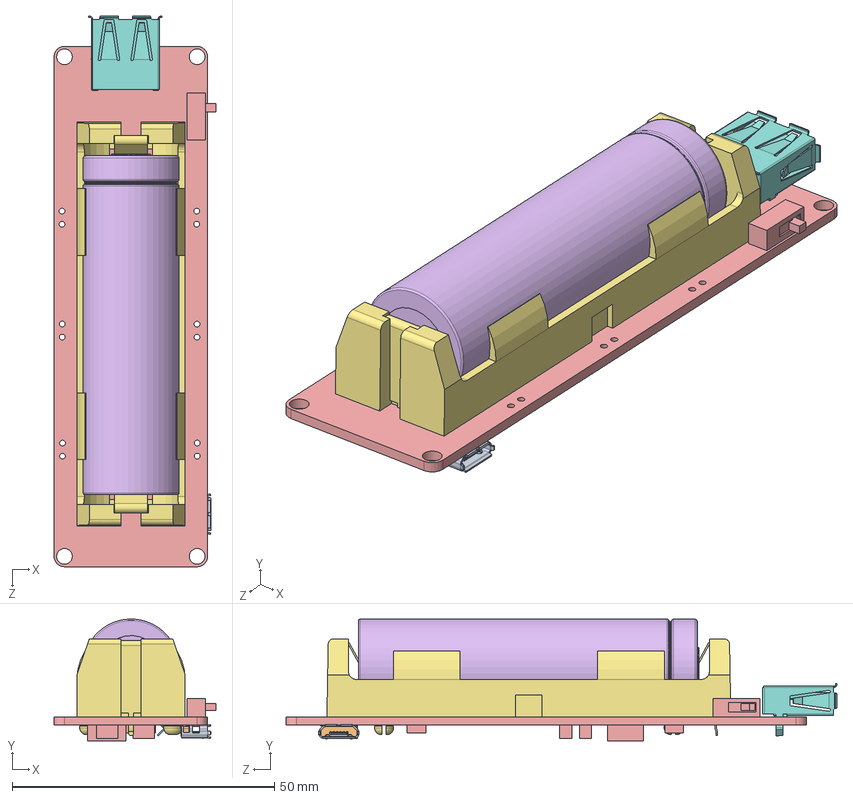
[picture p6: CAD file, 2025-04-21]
C prototipo/Extructura 3D/Archivos editables/Wemos Battery Shield V3.SLDASM
30.9 x 23.2 x 105.0 mm
shield.step
socket_housing.step
socket_plate.step
terminal.step x 5
Placa.step
PANASONIC_NCR-18650B.step
Battery Holder.step
Female USB.step

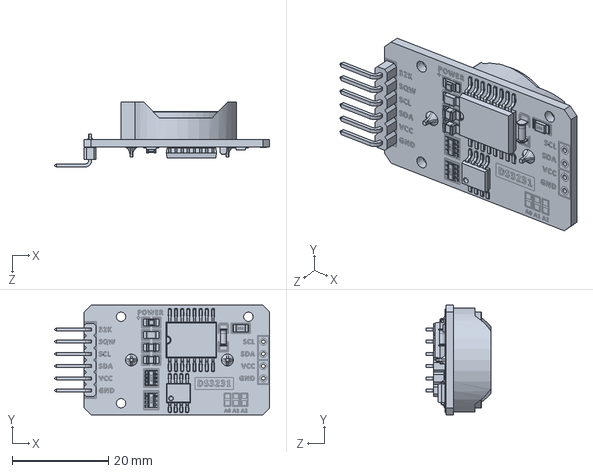
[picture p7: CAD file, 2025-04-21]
C prototipo/Extructura 3D/Archivos editables/DS3231 RTC.SLDASM
44.8 x 22.8 x 13.5 mm

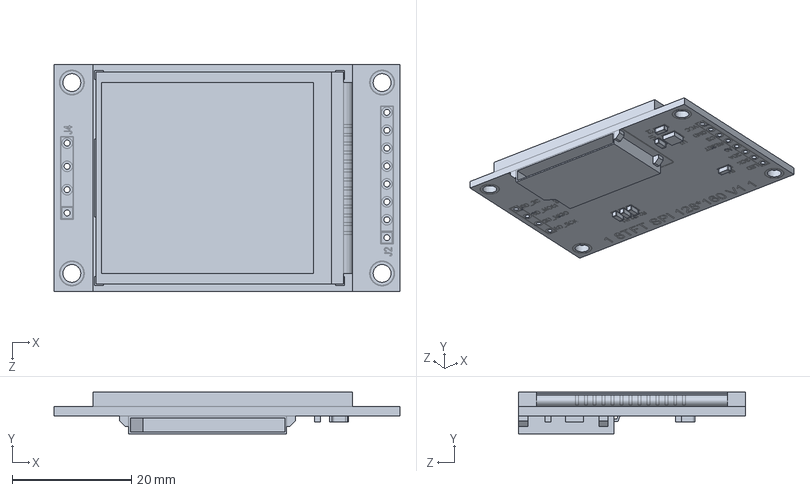
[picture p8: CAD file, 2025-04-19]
C prototipo/Extructura 3D/Archivos editables/LCD_TFT_1.8_SPI_ST7735.SLDASM
58.0 x 7.00 x 38.0 mm

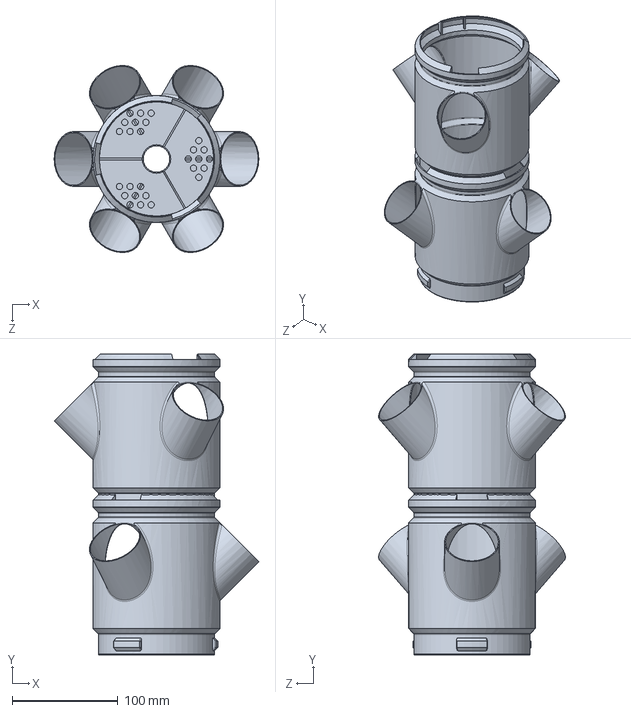
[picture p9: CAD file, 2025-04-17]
C prototipo/Extructura 3D/Archivos editables/Assem1.SLDASM
193.5 x 284.5 x 176.9 mm
cup_holder_fer x 2

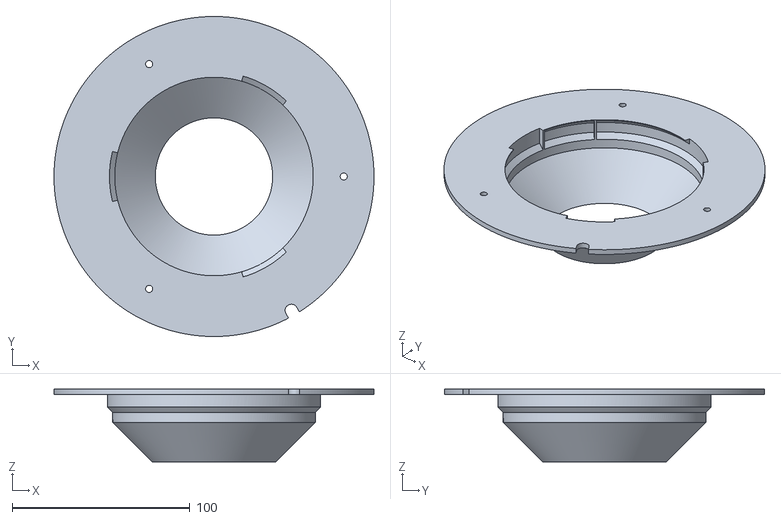
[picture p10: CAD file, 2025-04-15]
C prototipo/Extructura 3D/Adaptador.stl
180.0 x 180.0 x 41.0

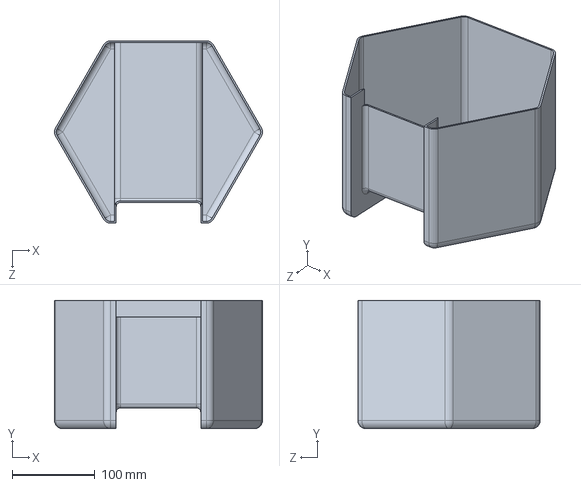
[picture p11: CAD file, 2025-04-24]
C prototipo/Extructura 3D/version 1_1/base 1_1.SLDPRT
250.9 x 155.0 x 220.0 mm

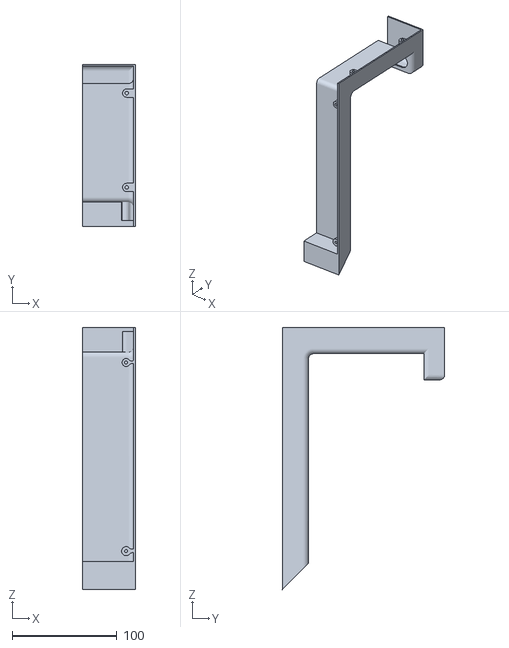
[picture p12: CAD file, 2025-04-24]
C prototipo/Extructura 3D/version 1_1/Impresiones/STL/box-control_I.STL
50.1 x 155.0 x 250.0

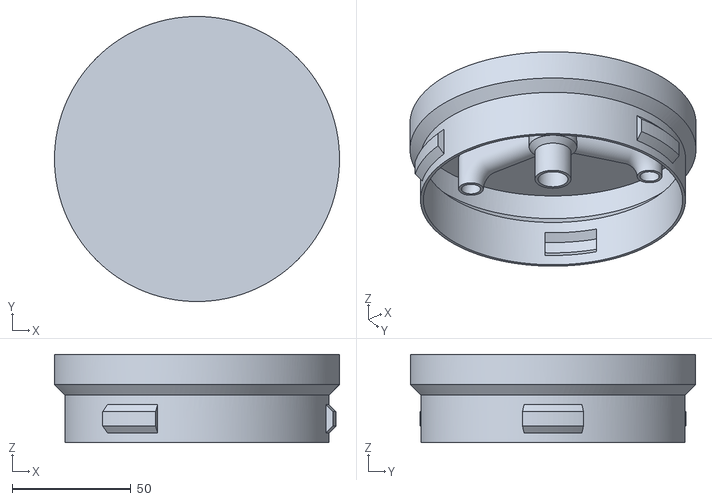
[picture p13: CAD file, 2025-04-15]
C prototipo/Extructura 3D/tapa.stl
120.0 x 120.0 x 37.1

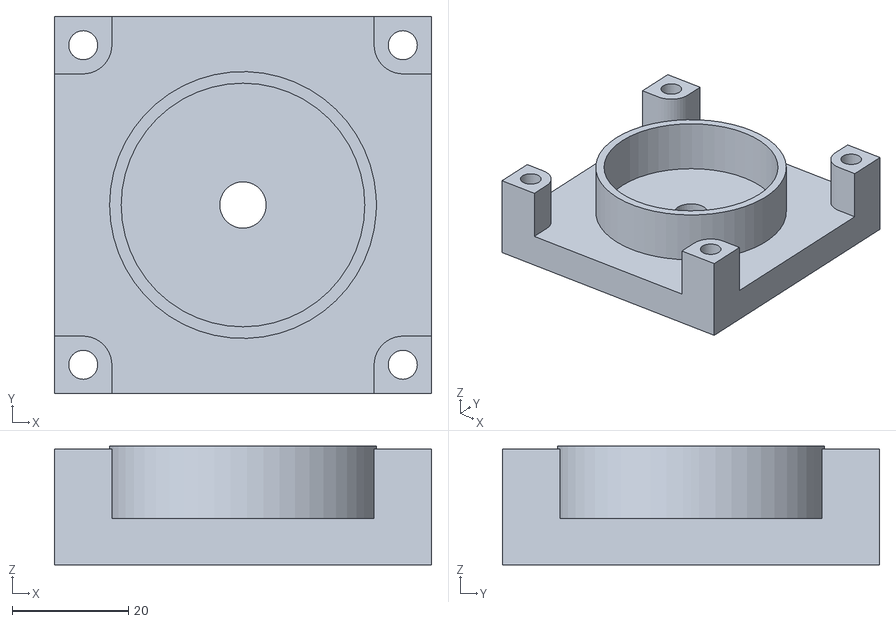
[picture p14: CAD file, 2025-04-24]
C prototipo/Extructura 3D/version 1_1/Impresiones/STL/chasis_perilla.STL
65.0 x 65.0 x 20.5

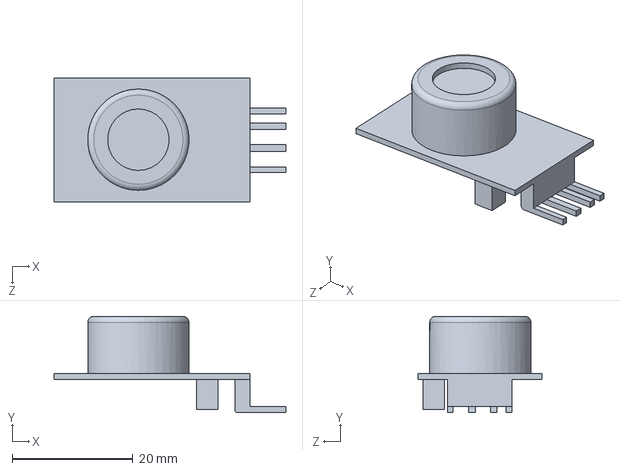
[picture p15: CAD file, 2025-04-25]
C prototipo/Extructura 3D/Archivos editables/MQ-7.SLDPRT
38.5 x 16.0 x 20.5 mm

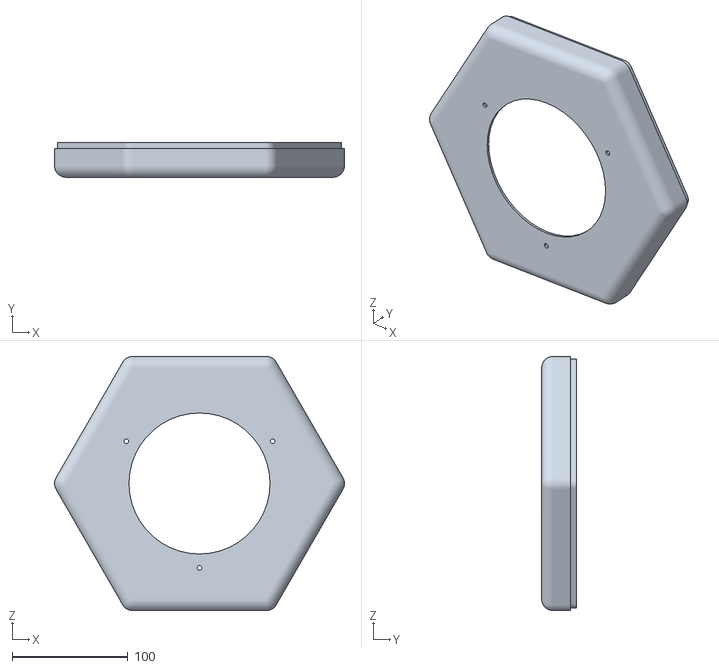
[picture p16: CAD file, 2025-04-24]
C prototipo/Extructura 3D/version 1_1/Impresiones/STL/techo_tanque.STL
250.9 x 30.0 x 220.0

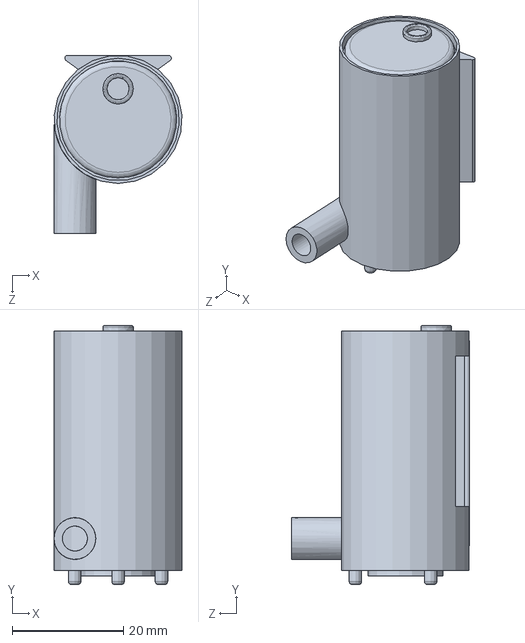
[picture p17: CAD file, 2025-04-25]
C prototipo/Extructura 3D/Archivos editables/mini_pump.SLDPRT
23.0 x 46.5 x 32.0 mm

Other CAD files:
C prototipo/Extructura 3D/Archivos editables/HC-SR04.sldasm
C prototipo/Extructura 3D/version 1_1/box-control_D.SLDPRT
C prototipo/Extructura 3D/version 1_1/techo_tanque.SLDPRT
C prototipo/Extructura 3D/version 1_1/box-control_I.SLDPRT
C prototipo/Extructura 3D/Archivos editables/20-Pin Header - Female - 2.54mm.SLDPRT
C prototipo/Extructura 3D/Archivos editables/20-Pin Header - Female - 2.54mm.step
C prototipo/Extructura 3D/Archivos editables/3_8 inch push connect flow meter.SLDPRT
C prototipo/Extructura 3D/Archivos editables/3_8 inch push connect flow meter.step
C prototipo/Extructura 3D/Archivos editables/AHT25.SLDPRT
C prototipo/Extructura 3D/Archivos editables/Componente1.sldprt
C prototipo/Extructura 3D/Archivos editables/DS18B20.SLDPRT
C prototipo/Extructura 3D/Archivos editables/DS18B20.stp
C prototipo/Extructura 3D/Archivos editables/Default.sldprt
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

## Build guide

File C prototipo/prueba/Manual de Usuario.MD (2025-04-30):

# 📝 **Manual de Usuario: Sistema Hidropónico Inteligente en ESP32**  

## 📌 **1. Introducción**  
Este sistema automatiza el monitoreo y control de cultivos hidropónicos mediante sensores de temperatura, humedad, pH, nivel de agua y luz. Su interfaz gráfica permite configurar parámetros y supervisar el estado del cultivo desde una pantalla TFT.  

## 📌 **2. Encendido del Sistema**  
1. Conecta el ESP32 a una fuente de alimentación.  
2. La pantalla mostrará el mensaje **"Iniciando..."** mientras se inicializan los módulos.  
3. Luego, se mostrará el **menú principal**, listo para la navegación.  

## 📌 **3. Menú Principal**  
El usuario puede navegar entre opciones utilizando **tres botones físicos**:  
✔ Botón **Izquierda**: Mueve la selección hacia arriba.  
✔ Botón **Derecha**: Mueve la selección hacia abajo.  
✔ Botón **Confirmar**: Ingresa a la opción seleccionada.  

Las opciones disponibles son:  
✅ **Monitoreo de sensores** – Muestra temperatura, humedad, pH y flujo de agua en tiempo real.  
✅ **Recetas de cultivo** – Permite seleccionar parámetros óptimos para distintos cultivos.  
✅ **Configuración WiFi** – Escanea redes disponibles y permite conectarse a una red nueva.  
✅ **Estado del sistema** – Indica si la bomba, luces y sensores están activos.  

## 📌 **4. Uso de las Recetas de Cultivo**  
Desde el menú de **Recetas**, el usuario puede:  
✔ **Seleccionar** una receta de cultivo para ajustar parámetros automáticamente.  
✔ **Editar** una receta y modificar sus valores (temperatura, pH, humedad, iluminación).  
✔ **Guardar** cambios para aplicarlos de inmediato.  

## 📌 **5. Conexión WiFi y MQTT**  
1. Accede a **Configuración WiFi** en el menú.  
2. Se mostrará una lista de redes disponibles.  
3. Usa los botones para seleccionar la red deseada.  
4. Ingresa la contraseña y confirma la conexión.  
5. Si la conexión es exitosa, el sistema se sincroniza con el servidor MQTT y comienza a enviar datos.  

## 📌 **6. Modo Automático vs. Manual**  
✔ **Modo Automático:** El sistema ajusta riego, iluminación y alarmas según las mediciones de los sensores.  
✔ **Modo Manual:** El usuario activa/desactiva la bomba y las luces desde el menú.  

## 📌 **7. Manejo de Alertas y Seguridad**  
Si algún sensor detecta condiciones fuera de los parámetros seguros (por ejemplo, agua insuficiente o pH extremo), el sistema:  
🚨 Muestra un aviso visual en pantalla.  
📡 Envía una alerta vía MQTT o LoRa a otros dispositivos conectados.  
💡 Recomienda una acción para corregir el problema.  

---

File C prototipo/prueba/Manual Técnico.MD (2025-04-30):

# 🛠️ **Manual Técnico: Hidroponia Inteligente en ESP32**  

## 📌 **1. Arquitectura del Sistema**  

El sistema hidroponía inteligente está basado en **ESP32**, y se organiza en módulos independientes para cada funcionalidad.  
La estructura del código se encuentra organizada en las siguientes carpetas:  

```plaintext
Hidroponia/
├── Hidroponia.ino               # Código principal
├── Configuración.h              # Configuración general
├── Configuración_avanzada.h     # Configuración avanzada
├── src/
│   ├── sensores/                # Módulos de sensores (pH, temperatura, nivel de agua, flujo)
│   ├── control/                 # Control automático de riego e iluminación
│   ├── pantalla/                # Interfaz de pantalla TFT y menús
│   ├── comunicacion/            # Conexiones WiFi, MQTT, BLE Mesh y LoRa Mesh
│   ├── rtc/                     # Manejo del reloj RTC
│   ├── recetas/                 # Gestión de recetas de cultivo
└── bibliotecas/                  # Librerías externas necesarias
```

Cada módulo es independiente, lo que permite modificar el código sin afectar otras partes del sistema.  

---

## 📌 **2. Inicialización del Sistema (`setup()`)**  

Cuando el ESP32 se enciende, ejecuta la función `setup()` en `Hidroponia.ino`, donde se realizan las siguientes acciones:  

✔ **Inicializar pantalla TFT** para mostrar información visual.  
✔ **Inicializar sensores** y realizar la primera medición.  
✔ **Conectar a WiFi y MQTT**, asegurando la comunicación con el servidor.  
✔ **Activar módulos de comunicación** (BLE Mesh y LoRa Mesh).  
✔ **Cargar recetas almacenadas en EEPROM** y aplicar los parámetros.  
✔ **Definir si el nodo funcionará como transmisor o receptor**, según `transmisor.h` y `receptor.h`.  
✔ **Inicializar RTC** para manejar la hora y permitir sincronización.  

---

## 📌 **3. Ciclo de Operación (`loop()`)**  

El código ejecuta un ciclo continuo en la función `loop()`, donde se realiza:  

✔ **Actualización de la pantalla TFT** con los datos más recientes.  
✔ **Gestión de botones físicos** para navegar entre los menús.  
✔ **Lectura de sensores** cada cierto intervalo (ejemplo: 5 segundos).  
✔ **Verificación de alarmas** si algún valor está fuera de los rangos seguros.  
✔ **Control automático** de bomba y luces según condiciones ambientales.  
✔ **Envío de datos** por MQTT si el nodo es transmisor.  
✔ **Recepción y ejecución de comandos** si el nodo es receptor.  
✔ **Sincronización de fecha y hora con RTC**.  

---

## 📌 **4. Comunicación del Sistema**  

### **🔹 Conexión WiFi y MQTT (`wifi_manager.h` y `comunicacion.h`)**  
- Se inicia WiFi con las credenciales guardadas en EEPROM.  
- Se conecta a un servidor MQTT.  
- Se suscribe a tópicos MQTT para recibir comandos.  
- Si hay desconexión, el sistema intenta reconectar automáticamente.  

### **🔹 Comunicación BLE Mesh (`ble_mesh.h`)**  
- Se configura un servidor BLE.  
- Se define un servicio y característica para enviar y recibir datos.  
- Cuando otro ESP32 envía datos, la función `onWrite()` los procesa y ejecuta acciones.  

### **🔹 Comunicación LoRa Mesh (`lora_mesh.h`)**  
- Se inicializa el módulo LoRa.  
- Se define una función para **enviar paquetes de datos LoRa** a otros nodos.  
- Se procesa la recepción de datos entrantes para ejecutar acciones en el nodo receptor.  

---

## 📌 **5. Modo Transmisor y Modo Receptor**  

📡 **Modo Transmisor (`transmisor.h`)**  
✔ Recoge datos de los sensores.  
✔ Envía los datos a otros dispositivos vía MQTT, LoRa o BLE.  

🎯 **Modo Receptor (`receptor.h`)**  
✔ Recibe datos de otros nodos.  
✔ Procesa los mensajes y ejecuta comandos (por ejemplo, activar iluminación).  

Estos modos pueden activarse o desactivarse con la variable `esNodoTransmisor` o `esNodoReceptor`.  

---

## 📌 **6. Almacenamiento de Recetas de Cultivo en EEPROM**  

Las recetas de cultivo se guardan en EEPROM y permiten modificar los parámetros sin necesidad de reprogramar el código.  

✔ **Estructura de receta (`recetas.h`)**  
```cpp
struct Receta {
    char nombre[20];
    float tempAgua;
    float tempAire;
    float humedad;
    float nivelAgua;
    float ph;
    bool iluminacion;
};
```
✔ **Carga y guardado en EEPROM (`recetas.cpp`)**  
```cpp
void cargarRecetas() {
    EEPROM.begin(512);
    EEPROM.get(0, recetas);
}
void guardarRecetas() {
    EEPROM.put(0, recetas);
    EEPROM.commit();
}
```

---

## 📌 **7. Expansión del Sistema (Agregar Sensores y Mejoras)**  

Para **agregar un sensor nuevo**, sigue estos pasos:  
1️⃣ **Define el pin en `sensores.h`**  
2️⃣ **Crea una función de lectura en `sensores.cpp`**  
3️⃣ **Modifica `loop()` en `Hidroponia.ino`** para llamar a la función periódicamente.  
4️⃣ **Si es necesario, envía los datos por MQTT en `transmisor.cpp`**  

Ejemplo para un sensor de CO2:  

### **Archivo: `sensores.h`**  
```cpp
#define SENSOR_CO2_PIN 37
```

### **Archivo: `sensores.cpp`**  
```cpp
float leerCO2() {
    return analogRead(SENSOR_CO2_PIN) * 0.1;
}
```

### **Modificación en `loop()` (`Hidroponia.ino`)**  
```cpp
float co2 = leerCO2();
Serial.println("CO2: " + String(co2));
```

### **Envío de datos MQTT en `transmisor.cpp`**  
```cpp
String datos = "{\"CO2\":" + String(co2) + "}";
client.publish("hidroponia/datos", datos.c_str());
```

---

## 📌 **8. Agregar Nuevas Automatizaciones**  

Para **agregar una automatización**, por ejemplo, ajuste de nutrientes según el pH:  

### **Archivo: `control.h`**  
```cpp
void ajustarNutrientes();
```

### **Archivo: `control.cpp`**  
```cpp
void ajustarNutrientes() {
    if (phValor < 5.8) {
        Serial.println("Agregando nutrientes alcalinos.");
    } else if (phValor > 7.2) {
        Serial.println("Agregando nutrientes ácidos.");
    } else {
        Serial.println("pH dentro del rango óptimo.");
    }
}
```

### **Llamada en `loop()` (`Hidroponia.ino`)**  
```cpp
ajustarNutrientes();
```

---

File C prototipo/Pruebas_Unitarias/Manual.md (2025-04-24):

## Manual de uso de directorio de pruebas unificada.

### Cual es la idea?
Para que no tengamos que crear un proyecto de platofmio nuevo por cada sensor, que ademas deberia incluir las funciones de conexion, probe crear un direcotiro, modulado con el que podamos crear el codigo de de cada sensor, pero cuando lo compilemos solo llamemos al/los que querramos testear. Sin tener que modificar las conexiones (excepto las credenciales/broker) 

### Conexiones
De momento, solo MQTT y Wifi. Busque crearlas asincronicas, de forma que corra lo que sea, sin problema en ese apartado.
Idealmente, se pueden agregar otras funciones de conexion y deberiamos tener que modificar demasiado el codigo

## Estructura del Directorio:

- 📦Pruebas_Unitarias
-  ┣ 📂.pio
-  ┣ 📂.vscode
-  ┣ 📂include              // Aca van las librerias creadas de mqtt, wifi, o las proximas conexiones o elementos fijos
-  ┃ ┣ 📜mqtt_async.h
-  ┃ ┣ 📜README
-  ┃ ┗ 📜wifi_async.h
-  ┣ 📂lib
-  ┃ ┗ 📜README
-  ┣ 📂src                  // Aca van las funciones correspondientes a los .h fijos tambien
-  ┣ ┗ 📂sensores             // Aca creamos la carpeta de los sensores que vayamos a testear. 
-  ┃ ┃┗ 📂sr04
-  ┃ ┃  ┣ 📜sr04.cpp
-  ┃ ┃  ┗ 📜sr04.h
-  ┃ ┣ 📜main.cpp
-  ┃ ┣ 📜mqtt_async.cpp
-  ┃ ┗ 📜wifi_async.cpp
-  ┣ 📂test
-  ┃ ┗ 📜README
-  ┣ 📜.gitignore
-  ┣ 📜Manual.md_
-  ┗ 📜platformio.ini       // Vamos a tener que modificar el src_filter cada vez que busquemos compilarlo para probar.

## Como usarlo
Como comente, la intencion es poder agregar uno a uno los sensores, agregar su correspondiente codigo y documentos, pero utilizar solo los que necesitemos em la prueba.

- Crear la carpeta y respectivos [sensor].h y [sensor].cpp
- Modificar el platforio.ini [src_filter]
    
    build_src_filter =
    +<*.cpp>                ; tus .cpp en la raíz de src/
    +<sensores/sr04/*.cpp>    ; todo lo que haya bajo src/sensores/ cambiarndo la carpeta "sr04" 

    // Creamos la bandera con el formato [-D]+SENSOR_[SENSOR] Queda algo como en el ejemplo
    build_flags = -DSENSOR_SR04

- Agregamos lo siguiente en el main:
    
    // Agregamos un **ifdef** + [flag]. Ahi incluimos el archivo.h indicando la direccion del que vayamos a usar y los pines.
    #ifdef SENSOR_SR04
    #include "sensores/sr04/sr04.h"
    #define TRIG_PIN 5
    #define ECHO_PIN 18
    #endif

    // Agregamos un **ifdef** + [flag] en el setup con el setup correspondiente para el sensor
    // Agregamos un **ifdef** + [flag] en el loop con las funciones correspondiente para el sensor

**NO HACE FALTA BORRAR FUNCIONES DE OTROS SENOSRES, SINO ESTA EL FLAG DEL PRINCIPIO, NO DEBERIAN INTERRUMPIR LA EJECUCION**

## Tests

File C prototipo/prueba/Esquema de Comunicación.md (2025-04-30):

# 📡 **Esquema de Comunicación del Sistema Hidropónico Inteligente en ESP32**  

## 📌 **1. Introducción**  
El sistema hidroponía inteligente utiliza varios protocolos de comunicación para el envío y recepción de datos en tiempo real. Dependiendo de la configuración, puede utilizar **WiFi, MQTT, BLE Mesh y LoRa Mesh** para conectar múltiples nodos ESP32 o enviar datos a servidores remotos.

### 🔹 **Tipos de Comunicación en el Sistema**
✔ **WiFi + MQTT** → Comunicación remota y almacenamiento de datos en servidores.  
✔ **BLE Mesh** → Comunicación entre nodos cercanos sin necesidad de Internet.  
✔ **LoRa Mesh** → Comunicación a larga distancia sin infraestructura de red.  
✔ **Modo Transmisor/Receptor** → Un nodo envía datos, otro los recibe y ejecuta acciones.  

---

## 📌 **2. Flujo de Datos dentro del Sistema**  

El ESP32 sigue un proceso de comunicación que se divide en **5 etapas:**  

```plaintext
1️⃣ Captura de datos de sensores → (Temperatura, pH, Nivel de agua, Luz, etc.)
2️⃣ Procesamiento de datos → (Verificación de umbrales y lógica de automatización)
3️⃣ Transmisión de datos → (Envía vía MQTT, BLE o LoRa según configuración)
4️⃣ Recepción de datos → (Nodo receptor procesa y ejecuta comandos)
5️⃣ Respuesta y ajustes → (Activación de bomba, ajuste de iluminación, alarmas)
```

---

## 📌 **3. Comunicación WiFi y MQTT**  

El protocolo MQTT permite enviar datos a servidores remotos y recibir comandos de control.  

### **🔹 Proceso de conexión a MQTT (`wifi_manager.h` y `comunicacion.h`)**  
✔ El ESP32 se conecta a WiFi y verifica la señal.  
✔ Se conecta al **servidor MQTT**, enviando credenciales de usuario.  
✔ Se suscribe a tópicos para recibir comandos (`hidroponia/control`).  
✔ Publica datos en **hidroponia/datos** cada vez que toma una nueva medición.  

### **🔹 Ejemplo de envío de datos vía MQTT (`transmisor.cpp`)**  
```cpp
String datos = "{\"tempAgua\":" + String(temperaturaAgua) + ",\"ph\":" + String(phValor) + "}";
client.publish("hidroponia/datos", datos.c_str());
```

### **🔹 Ejemplo de recepción y ejecución de comandos (`receptor.cpp`)**  
```cpp
void procesarDatos(const char* mensaje) {
    if (strstr(mensaje, "\"iluminacion\":true")) {
        activarIluminacion(true);
        Serial.println("Comando recibido: Activar iluminación.");
    }
}
```

---

## 📌 **4. Comunicación BLE Mesh**  

El protocolo **BLE Mesh** permite que múltiples ESP32 intercambien información de manera local, sin necesidad de una red WiFi.  

### **🔹 Inicialización de BLE Mesh (`ble_mesh.h` y `ble_mesh.cpp`)**  
✔ Se define un **servidor BLE** con un servicio y característica.  
✔ Se habilita el envío y recepción de datos entre nodos.  
✔ Cuando otro ESP32 transmite información, se recibe y se procesa el mensaje.  

### **🔹 Ejemplo de envío de datos vía BLE Mesh (`ble_mesh.cpp`)**  
```cpp
void enviarDatosBLE(const String& datos) {
    if (pCharacteristic != nullptr) {
        pCharacteristic->setValue(datos.c_str());
        pCharacteristic->notify();
    }
}
```

### **🔹 Ejemplo de recepción de datos en BLE Mesh (`ble_mesh.cpp`)**  
```cpp
class MyBLECallbacks: public BLECharacteristicCallbacks {
  void onWrite(BLECharacteristic *pCharacteristic) override {
      std::string value = pCharacteristic->getValue();
      if (!value.empty()) {
          Serial.println("Mensaje recibido vía BLE: " + String(value.c_str()));
      }
  }
};
```

---

## 📌 **5. Comunicación LoRa Mesh**  

LoRa Mesh permite que el ESP32 envíe y reciba datos a larga distancia, ideal para ambientes agrícolas sin infraestructura WiFi.  

### **🔹 Configuración de LoRa Mesh (`lora_mesh.h` y `lora_mesh.cpp`)**  
✔ Se inicializa el módulo **LoRa SX1278** con frecuencia 915 MHz (ajustable según región).  
✔ Se establece una función para enviar paquetes de datos a otros nodos.  
✔ Se procesa la recepción de mensajes entrantes y se ejecutan comandos si es necesario.  

### **🔹 Ejemplo de envío de datos en LoRa Mesh (`lora_mesh.cpp`)**  
```cpp
void enviarDatosLoRa(const String& datos) {
    LoRa.beginPacket();
    LoRa.print(datos);
    LoRa.endPacket();
}
```

### **🔹 Ejemplo de recepción de datos en LoRa Mesh (`lora_mesh.cpp`)**  
```cpp
void recibirDatosLoRa() {
    int packetSize = LoRa.parsePacket();
    if (packetSize) {
        String mensaje = "";
        while (LoRa.available()) {
            mensaje += (char)LoRa.read();
        }
        Serial.println("Mensaje recibido vía LoRa: " + mensaje);
    }
}
```

---

## 📌 **6. Modos de Operación: Transmisor y Receptor**  

📡 **Modo Transmisor (`transmisor.h`)**  
✔ Recopila datos de los sensores.  
✔ Envía los datos a otros dispositivos.  

🎯 **Modo Receptor (`receptor.h`)**  
✔ Recibe datos y ejecuta comandos.  
✔ Modifica configuraciones según el mensaje recibido.  

✔ Para activar o desactivar estos modos, se modifican las variables:  
```cpp
bool esNodoTransmisor = true;
bool esNodoReceptor = false;
```

---

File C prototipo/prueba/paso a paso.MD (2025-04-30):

- **Informe 1:** Explica cómo trabaja el programa paso por paso, desde la inicialización hasta la ejecución en el ESP32.  
- **Informe 2:** Explica cómo se pueden hacer ediciones para agregar mejoras al sistema.  

---

# 📝 **Informe 1: Funcionamiento del Programa Paso a Paso**  

## 📌 **1. Inicio y Configuración Inicial**  

Cuando el ESP32 se inicia, se ejecuta la función `setup()`. Esta sección se encarga de:  

1. **Inicializar la comunicación serial** para debug.  
2. **Inicializar la pantalla TFT** para la interfaz gráfica.  
3. **Inicializar sensores** (DHT11, DS18B20, nivel de agua, caudalímetro, pH, etc.).  
4. **Inicializar control de automatización** (bomba de agua, luces, alarmas).  
5. **Conectar a WiFi** y, si es necesario, a MQTT para recibir y enviar datos.  
6. **Activar módulos de comunicación** (BLE Mesh, LoRa Mesh).  
7. **Cargar recetas desde EEPROM** para aplicar parámetros de cultivo preconfigurados.  
8. **Definir si el nodo actúa como transmisor o receptor** (esto se configura en `transmisor.h` y `receptor.h`).  
9. **Inicializar RTC** para manejar fecha y hora correctamente.  

Todo esto ocurre una sola vez al arrancar el ESP32.  

## 📌 **2. Ejecución Cíclica en `loop()`**  

Después de la inicialización, el programa entra en un ciclo de ejecución infinita dentro de `loop()`. En cada ciclo se realizan varias tareas:  

✔ **Actualizar pantalla TFT** con los últimos datos obtenidos.  
✔ **Manejar la entrada de botones** para navegar en los menús.  
✔ **Mantener activa la conexión WiFi y MQTT**.  
✔ **Leer sensores** (temperatura, pH, nivel de agua, flujo, luz, gas, corriente).  
✔ **Ejecutar control automático** según los umbrales configurados:  
   - Si el **nivel de agua es bajo**, activa la bomba.  
   - Si la **luz es insuficiente**, activa la iluminación artificial.  
   - Si el **pH está fuera de rango**, envía una alerta.  
✔ **Verificar alarmas** y enviar notificaciones si se detectan valores peligrosos.  
✔ **Transmitir datos** si el nodo es transmisor.  
✔ **Recibir datos y ejecutar comandos** si el nodo es receptor.  
✔ **Actualizar hora con RTC** y sincronizar si hay conexión MQTT.  

Este ciclo se repite indefinidamente, asegurando que el sistema siempre esté monitoreando y actuando según los datos que recibe.  

## 📌 **3. Modos de Operación**  

El programa admite dos modos de operación:  

1️⃣ **Modo Transmisor:** Recoge datos de sensores y los envía vía MQTT, LoRa o BLE.  
2️⃣ **Modo Receptor:** Procesa los datos recibidos y ejecuta acciones en respuesta (por ejemplo, activando la iluminación o modificando la frecuencia de riego).  

## 📌 **4. Menús y Configuración desde Pantalla**  

El usuario puede usar los botones físicos para:  

✔ **Activar o desactivar sensores** desde el menú de configuración.  
✔ **Seleccionar una receta de cultivo** con parámetros específicos.  
✔ **Sincronizar WiFi** desde una lista de redes disponibles.  
✔ **Visualizar alertas y estados del sistema**.  

## 📌 **5. Comunicación entre Dispositivos**  

El ESP32 puede comunicarse de varias formas:  
✔ **WiFi + MQTT:** Para enviar datos a la nube o recibir comandos remotos.  
✔ **BLE Mesh:** Para conectarse con otros nodos ESP32 cercanos.  
✔ **LoRa Mesh:** Para comunicación a larga distancia sin WiFi.  

Si el sistema detecta una desconexión en WiFi o MQTT, intentará reconectar automáticamente.  

---

# 🛠️ **Informe 2: Cómo Hacer Ediciones y Agregar Mejoras**  

El proyecto está diseñado para ser **modular**, lo que significa que cada funcionalidad está separada en su propio archivo. Esto facilita la edición y la ampliación del sistema sin afectar otros módulos.  

## 📌 **1. Cómo Agregar un Nuevo Sensor**  

Para agregar un nuevo sensor:  

1️⃣ **Define su pin en `sensores.h`**, por ejemplo:  
```cpp
#define SENSOR_CO2_PIN 37
```
2️⃣ **Crea una función para leer el sensor en `sensores.cpp`**, ejemplo:  
```cpp
float leerCO2() {
    return analogRead(SENSOR_CO2_PIN) * 0.1;
}
```
3️⃣ **Actualiza `loop()` en `Hidroponia.ino`** para leer el nuevo sensor periódicamente:  
```cpp
float co2 = leerCO2();
Serial.println("CO2: " + String(co2));
```
4️⃣ **Envía los datos por MQTT** en `transmisor.cpp`:  
```cpp
String datos = "{\"CO2\":" + String(co2) + "}";
client.publish("hidroponia/datos", datos.c_str());
```

---

## 📌 **2. Cómo Agregar un Nuevo Menú en Pantalla**  

Si necesitas agregar un nuevo menú, por ejemplo, para estadísticas avanzadas:  

1️⃣ **Crea una nueva pantalla en `menu.h`**, por ejemplo:  
```cpp
void mostrarMenuEstadisticas();
```
2️⃣ **Define la lógica del menú en `menu.cpp`**, ejemplo:  
```cpp
void mostrarMenuEstadisticas() {
    tft.fillScreen(ST7735_BLACK);
    tft.setCursor(10, 10);
    tft.setTextSize(1);
    tft.setTextColor(ST7735_WHITE);
    tft.println("[ ESTADÍSTICAS ]");
    tft.println("Promedio de pH: " + String(promedioPH));
    tft.println("Flujo medio: " + String(promedioFlujoAgua));
}
```
3️⃣ **Agrega la opción en el menú principal (`menu.cpp`)**:  
```cpp
tft.println(opcionMenu == 4 ? "> Estadísticas" : "  Estadísticas");
```
4️⃣ **Maneja la selección del nuevo menú** en `menu.cpp`:  
```cpp
if (opcionMenu == 4) mostrarMenuEstadisticas();
```

---

## 📌 **3. Cómo Agregar una Nueva Función Automática**  

Si necesitas agregar una automatización nueva, como el control de nutrientes basado en el pH:  

1️⃣ **Agrega la lógica en `control.h`**, por ejemplo:  
```cpp
void ajustarNutrientes();
```
2️⃣ **Define la función en `control.cpp`**, ejemplo:  
```cpp
void ajustarNutrientes() {
    if (phValor < 5.8) {
        Serial.println("Agregando nutrientes alcalinos.");
    } else if (phValor > 7.2) {
        Serial.println("Agregando nutrientes ácidos.");
    } else {
        Serial.println("pH dentro del rango óptimo.");
    }
}
```
3️⃣ **Llama a la función desde `loop()` en `Hidroponia.ino`**:  
```cpp
ajustarNutrientes();
```

---

## 📌 **4. Cómo Modificar el Sistema de Comunicación**  

Si deseas enviar datos no solo por MQTT, sino también por LoRa y BLE simultáneamente:  

1️⃣ **Modifica `transmisor.cpp`** para incluir ambos envíos:  
```cpp
void enviarDatos() {
    if (!esNodoTransmisor) return;
    
    String datos = "{\"tempAgua\":" + String(temperaturaAgua) + "}";

    client.publish("hidroponia/datos", datos.c_str());  // Enviar por MQTT
    enviarDatosLoRa(datos);  // Enviar por LoRa
    enviarDatosBLE(datos);  // Enviar por BLE
}
```
2️⃣ **Asegúrate de que las funciones `enviarDatosLoRa()` y `enviarDatosBLE()` estén activas**.  

---

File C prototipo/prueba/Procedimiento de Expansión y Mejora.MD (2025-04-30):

# 🏗️ **Procedimiento de Expansión y Mejora: Hidroponia Inteligente en ESP32**  

## 📌 **1. Introducción**  
Este documento describe cómo se pueden modificar y mejorar los diferentes módulos del sistema hidropónico, permitiendo agregar nuevos sensores, ampliar la comunicación y optimizar la automatización.  

El sistema está diseñado en **arquitectura modular**, lo que significa que cada funcionalidad es independiente y puede ser modificada sin afectar el resto del código.  

---

## 📌 **2. Agregar un Nuevo Sensor al Sistema**  

Para agregar un nuevo sensor, sigue estos pasos:  

### **1️⃣ Definir el nuevo sensor en `sensores.h`**  
Agrega el pin en el archivo `sensores.h`, por ejemplo, si deseas incluir un sensor de **CO2**:  
```cpp
#define SENSOR_CO2_PIN 37
```

### **2️⃣ Crear la función de lectura en `sensores.cpp`**  
Define la función para leer los datos del sensor:  
```cpp
float leerCO2() {
    return analogRead(SENSOR_CO2_PIN) * 0.1; // Ajustar según el sensor específico
}
```

### **3️⃣ Modificar `loop()` en `Hidroponia.ino`**  
Agrega la lectura del sensor en cada ciclo de ejecución del ESP32:  
```cpp
float co2 = leerCO2();
Serial.println("CO2: " + String(co2));
```

### **4️⃣ Enviar los datos vía MQTT en `transmisor.cpp`**  
Si el sistema está conectado a la nube, puedes enviar los datos del nuevo sensor por MQTT:  
```cpp
String datos = "{\"CO2\":" + String(co2) + "}";
client.publish("hidroponia/datos", datos.c_str());
```

✔ **Con estos pasos, el nuevo sensor se integrará al sistema sin afectar las demás funciones.**  

---

## 📌 **3. Agregar un Nuevo Menú en la Pantalla TFT**  

Si necesitas un nuevo menú para mostrar información específica, sigue estos pasos:  

### **1️⃣ Definir el nuevo menú en `menu.h`**  
```cpp
void mostrarMenuEstadisticas();
```

### **2️⃣ Implementar el menú en `menu.cpp`**  
```cpp
void mostrarMenuEstadisticas() {
    tft.fillScreen(ST7735_BLACK);
    tft.setCursor(10, 10);
    tft.setTextSize(1);
    tft.setTextColor(ST7735_WHITE);
    tft.println("[ ESTADÍSTICAS ]");
    tft.println("Promedio de pH: " + String(promedioPH));
    tft.println("Flujo medio: " + String(promedioFlujoAgua));
}
```

### **3️⃣ Agregar la opción en el menú principal (`menu.cpp`)**  
```cpp
tft.println(opcionMenu == 4 ? "> Estadísticas" : "  Estadísticas");
```

### **4️⃣ Manejar la selección del nuevo menú**  
```cpp
if (opcionMenu == 4) mostrarMenuEstadisticas();
```

✔ **Este método permite expandir el menú sin modificar otros módulos del sistema.**  

---

## 📌 **4. Agregar una Nueva Automatización**  

Si deseas mejorar el control del sistema agregando una función para **ajustar nutrientes según el pH**, sigue estos pasos:  

### **1️⃣ Definir la nueva lógica en `control.h`**  
```cpp
void ajustarNutrientes();
```

### **2️⃣ Implementar la función en `control.cpp`**  
```cpp
void ajustarNutrientes() {
    if (phValor < 5.8) {
        Serial.println("Agregando nutrientes alcalinos.");
    } else if (phValor > 7.2) {
        Serial.println("Agregando nutrientes ácidos.");
    } else {
        Serial.println("pH dentro del rango óptimo.");
    }
}
```

### **3️⃣ Llamar a la función en `loop()` en `Hidroponia.ino`**  
```cpp
ajustarNutrientes();
```

✔ **Este método permite agregar funciones de automatización sin cambiar la estructura base del código.**  

---

## 📌 **5. Optimización de la Comunicación**  

Si deseas enviar datos no solo por MQTT, sino también por **LoRa Mesh y BLE Mesh simultáneamente**, puedes hacerlo modificando `transmisor.cpp`:  

```cpp
void enviarDatos() {
    if (!esNodoTransmisor) return;
    
    String datos = "{\"tempAgua\":" + String(temperaturaAgua) + "}";

    client.publish("hidroponia/datos", datos.c_str());  // MQTT
    enviarDatosLoRa(datos);  // LoRa Mesh
    enviarDatosBLE(datos);  // BLE Mesh
}
```

✔ **Este método permite que el ESP32 comunique los datos por múltiples canales sin modificar el resto del sistema.**  

---

## 📌 **6. Agregar Más Recetas de Cultivo**  

Si deseas ampliar la cantidad de recetas almacenadas en **EEPROM**, sigue estos pasos:  

### **1️⃣ Modificar `recetas.h` para aumentar el límite**  
```cpp
#define MAX_RECETAS 10 // Cambia el número según lo necesario
```

### **2️⃣ Agregar nuevas recetas en `recetas.cpp`**  
```cpp
Receta recetas[MAX_RECETAS] = {
    {"Lechuga", 20.0, 22.0, 70.0, 10.0, 6.2, true},
    {"Tomate", 22.0, 25.0, 65.0, 15.0, 5.8, true},
    {"Albahaca", 21.0, 23.0, 75.0, 12.0, 6.5, true},
    {"Perejil", 19.0, 21.0, 80.0, 8.0, 6.0, false},
    {"Fresas", 20.0, 24.0, 68.0, 12.0, 5.5, true},
    {"Menta", 18.5, 21.0, 77.0, 9.0, 6.3, true},
    {"Cilantro", 20.0, 22.5, 79.0, 10.5, 6.1, false},
    {"Pimiento", 23.0, 26.0, 60.0, 14.0, 5.7, true},
    {"Espinaca", 19.0, 22.0, 75.0, 10.0, 6.4, false},
    {"Frambuesas", 20.5, 23.5, 69.0, 11.0, 5.6, true}
};
```

✔ **Este método permite expandir la lista de cultivos sin afectar la lógica del sistema.**  

---

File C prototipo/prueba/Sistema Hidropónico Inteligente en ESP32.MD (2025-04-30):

# 📝 **Resumen Ejecutivo: Sistema Hidropónico Inteligente en ESP32**  

## 📌 **1. Introducción**  
Este sistema hidroponía inteligente basado en **ESP32** permite la automatización del monitoreo y control de un sistema hidropónico, integrando sensores ambientales y de agua, conectividad inalámbrica para transmisión de datos y una interfaz gráfica interactiva.  

## 📌 **2. Objetivos del Proyecto**  
✔ Optimizar el riego y la iluminación artificial de cultivos hidropónicos.  
✔ Monitorizar variables clave como temperatura, humedad, pH y nivel de agua.  
✔ Permitir comunicación remota mediante **WiFi, MQTT, BLE Mesh y LoRa Mesh**.  
✔ Facilitar la selección de recetas de cultivo para ajustar parámetros automáticamente.  

## 📌 **3. Funcionalidades Principales**  
✅ **Sensores y monitoreo** de temperatura, humedad, pH, flujo y nivel de agua.  
✅ **Control automático** de bomba de agua y luces según condiciones del entorno.  
✅ **Conectividad múltiple** (WiFi, BLE, LoRa) para transmisión y recepción de datos.  
✅ **Interfaz gráfica** con pantalla TFT y menú interactivo para configuraciones.  
✅ **Gestión de recetas** predefinidas con parámetros óptimos para distintos cultivos.  

## 📌 **4. Ventajas del Sistema**  
✔ **Flexibilidad y escalabilidad** – Modificación sencilla de configuraciones y expansión de sensores.  
✔ **Reducción de costos** – Optimización del uso de agua y energía en el cultivo hidropónico.  
✔ **Monitoreo remoto** – Permite supervisión a distancia mediante MQTT o BLE Mesh.  
✔ **Interacción intuitiva** – Menús gráficos con opciones de configuración en pantalla.  

## 📌 **5. Aplicaciones Prácticas**  
🔹 **Hidroponía doméstica y profesional** – Automatización para cultivos caseros o de gran escala.  
🔹 **Agricultura inteligente** – Integración con otros sistemas de IoT agrícola.  
🔹 **Laboratorios y pruebas científicas** – Registro y análisis de datos ambientales y de cultivo.  

---

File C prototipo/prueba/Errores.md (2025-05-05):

# Detalle de Errores y mensajes de Alarma

### Errores: 

| Código | Nombre | Mensaje |
| --- | --- | --- |
| 0 | NONE | OK |
| 1 | WIFI_INIT_FAIL | Error al inicializar WiFi |
| 2 | WIFI_AVAILABLE_NW_FAIL | Error al escanear redes WiFi |
| 3 | WIFI_CONNECT_FAIL | Error al conectar a la red WiFi |
| 4 | WIFI_CRED_SAVE_FAIL | Error al guardar credenciales WiFi |
| 5 | LORA_INIT_FAIL | Error al inicializar LoRa Mesh |
| 6 | LORA_SEND_FAIL | Error al enviar datos por LoRa |
| 7 | LORA_GET_FAIL | Error al recibir datos por LoRa |
| 8 | GSM_INIT_FAIL | Error al inicializar módulo GSM |
| 9 | GSM_LOOP_FAIL | Error en bucle GSM |
| 10 | GSM_STATE_FAIL | Estado GSM inválido |
| 11 | GSM_MQTTClient_FAIL | Error al obtener cliente MQTT sobre GSM |
| 12 | BLE_INIT_FAIL | Error al inicializar BLE Mesh |
| 13 | BLE_SEND_FAIL | Error al enviar datos por BLE |
| 14 | BLE_GET_FAIL | Error al recibir datos por BLE |
| 15 | MQTT_INIT_FAIL | Error al inicializar conexión MQTT |
| 16 | MQTT_SEND_FAIL | Error al enviar datos por MQTT |
| 17 | RMENU_INIT_FAIL | Error al inicializar menú de Recetas |
| 18 | RMENU_MANAGE_FAIL | Error al gestionar selección de receta |
| 19 | WMENU_INIT_FAIL | Error al inicializar menú de WiFi |
| 20 | WMENU_MANAGE_FAIL | Error al gestionar selección de WiFi |
| 21 | PMENU_INIT_FAIL | Error al inicializar menú Principal |
| 22 | PMENU_MANAGE_FAIL | Error al procesar entrada del menú |
| 23 | PMENU_SHOW_MSG_FAIL | Error al mostrar mensaje en menú Principal |
| 24 | SENS_INIT_FAIL | Error al inicializar sensores |
| 25 | SENS_TEMP_AGUA_FAIL | Error al leer temperatura del agua |
| 26 | SENS_DTH_FAIL | Error al leer sensor DHT |
| 27 | SENS_NIVEL_AGUA_FAIL | Error al leer nivel de agua |
| 28 | SENS_FLUJO_AGUA_FAIL | Error al calcular flujo de agua |
| 29 | SENS_LUZ_FAIL | Error al leer intensidad de luz |
| 30 | SENS_GAS_FAIL | Error al leer sensor de gas |
| 31 | SENS_CORRIENTE_FAIL | Error al leer sensor de corriente |
| 32 | SENS_PH_FAIL | Error al leer sensor de pH |
| 33 | CONTROL_INIT_FAIL | Error al inicializar módulo de Control |
| 34 | CONTROL_ACT_BOMBA_FAIL | Error al activar bomba |
| 35 | CONTROL_ACT_LUCES_FAIL | Error al activar iluminación |
| 36 | CONTROL_VERIF_ALARM_FAIL | Error al verificar alarmas |
| 37 | CONTROL_NOTIF_ESTADO_FAIL | Error al notificar estado |
| 38 | CONTROL_AUTO_FAIL | Error en rutina de control automático |
| 39 | DISPLAY_INIT_FAIL | Error al inicializar pantalla |
| 40 | DISPLAY_UPDATE_FAIL | Error al actualizar pantalla |
| 41 | DISPLAY_SHOW_MSG_FAIL | Error al mostrar mensaje en pantalla |
| 42 | DISPLAY_SHOW_DATA_FAIL | Error al mostrar datos en pantalla |
| 43 | DISPLAY_SHOW_STANDBY_FAIL | Error al mostrar modo standby |
| 44 | DISPLAY_SHOW_ALERTA_FAIL | Error al mostrar alerta de agua |
| 45 | DISPLAY_BOTONES_FAIL | Error al manejar botones de la pantalla |
| 46 | DISPLAY_DASHBOARD_FAIL | Error al inicializar dashboard en pantalla |
| 47 | RECEPTOR_INIT_FAIL | Error al inicializar receptor |
| 48 | RECEPTOR_PROCESAR_FAIL | Error al procesar datos del receptor |
| 49 | RTC_INIT_FAIL | Error al inicializar RTC |
| 50 | RTC_GET_HORA_FAIL | Error al obtener hora del RTC |
| 51 | RTC_SET_HORA_FAIL | Error al sincronizar hora del RTC |
| 52 | TRANSMISOR_INIT_FAIL | Error al inicializar transmisor |
| 53 | TRANSMISOR_ENVIAR_FAIL | Error al enviar datos con el transmisor |
| 54 | RECETAS_CARGAR_FAIL | Error al cargar recetas |
| 55 | RECETAS_GUARDAR_FAIL | Error al guardar recetas |
| 57 | RECETAS_SELECCIONAR_FAIL | Error al seleccionar receta |
| 58 | RECETAS_MOSTRAR_FAIL | Error al mostrar receta actual |

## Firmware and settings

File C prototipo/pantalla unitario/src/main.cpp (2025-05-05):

#include <Arduino.h>
#include <HardwareSerial.h>

// Definir pines del SIM800L
#define RX_PIN 16  // RX del ESP32 conectado a TX del SIM800L
#define TX_PIN 17  // TX del ESP32 conectado a RX del SIM800L

// Inicializar HardwareSerial en UART2
HardwareSerial sim800l(2);

void setup() {
    Serial.begin(9600);  // Configuración del Monitor Serie
    sim800l.begin(9600, SERIAL_8N1, RX_PIN, TX_PIN);  // Comunicación con SIM800L

    Serial.println("🔍 Inicializando módulo SIM800L...");
    delay(3000);  // Esperar arranque del módulo

    // Prueba inicial con comando AT
    sim800l.println("AT");
}

void loop() {
    // Mostrar en el Monitor Serie la respuesta del SIM800L
    while (sim800l.available()) {
        Serial.write(sim800l.read());
    }

    // Permitir enviar comandos AT desde el Monitor Serie al SIM800L
    if (Serial.available()) {
        String command = Serial.readStringUntil('\n');  // Leer comando del usuario
        sim800l.println(command);  // Enviar comando AT al SIM800L
    }

    delay(100);
}

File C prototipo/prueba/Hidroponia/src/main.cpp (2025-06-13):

#include <Arduino.h>

// Módulos del sistema
#include "pantalla.h"
#include "sensores.h"
#include "control.h"
#include "comunicacion.h"
#include "rtc.h"
#include "recetas.h"
#include "menu.h"
#include "menu_recetas.h"
#include "menu_wifi.h"
#include "transmisor.h"
#include "receptor.h"
#include "gsm_async.h"
#include "wifi_manager.h"
#include "mqtt_async.h"

// Variables globales
unsigned long ultimaLectura = 0;
const unsigned long intervaloLectura = 5000;
extern bool pantallaNecesitaActualizacion;
bool menuVisible = false;  // Asegurar inicialización

void setupPantalla() {
  SPI.begin(TFT_CLK, TFT_MISO, TFT_MOSI, TFT_CS);
  tft.initR(INITR_BLACKTAB);
  tft.fillScreen(ST7735_BLACK);
  tft.setTextColor(ST7735_WHITE);
  tft.setTextSize(1);
  tft.fillRect(0, 150, 128, 10, BROWN);

  for (int altura = 5; altura <= 80; altura += 3) {
    tft.fillRect(55, 140 - altura, 18, altura, DARK_GREEN);
    tft.fillRect(55, 140 - altura, 18, altura - 4, LIGHT_GREEN);

    if (altura > 15) {
      tft.fillCircle(45, 140 - altura, 10, LIGHT_GREEN);
      tft.fillCircle(75, 140 - altura, 10, LIGHT_GREEN);
      tft.fillRect(45, 140 - altura - 5, 30, 10, LIGHT_GREEN);
    }
    if (altura > 30) {
      tft.fillCircle(40, 140 - altura - 10, 12, DARK_GREEN);
      tft.fillCircle(80, 140 - altura - 10, 12, DARK_GREEN);
      tft.fillRect(40, 140 - altura - 15, 40, 12, DARK_GREEN);
    }
    if (altura > 50) {
      tft.fillCircle(55, 140 - altura - 15, 14, LIGHT_GREEN);
      tft.fillCircle(73, 140 - altura - 15, 14, LIGHT_GREEN);
      tft.fillRect(55, 140 - altura - 20, 18, 14, LIGHT_GREEN);
    }

    delay(250);
  }

  tft.fillCircle(64, 40, 8, RED);
  tft.fillCircle(64, 40, 6, ORANGE);
  tft.fillCircle(64, 40, 4, YELLOW);
  delay(5000);
}

void setup() {
  Serial.begin(9600);
  delay(1000);
  Serial.println(" Iniciando sistema hidroponico...");

  // Pantalla bienvenida
  setupPantalla();

  // Espera a que WiFi se establezca completamente
  conectarWiFi();
  
  // Asegura que WiFi esté completamente establecido
  delay(1000);

  // Configuración MQTT
  mqttSetup(MQTT_BROKER, MQTT_PORT);
  mqttSetCallback(recibirMensajeMQTT);
  
  // Intenta conectar directamente
  Serial.println("Conectando directamente a MQTT...");
  getMqttClient().connect();
  
  // Suscripción a temas (solo después de conectar)
  mqttSubscribe("hidroponia/control", 1);


  // Sistema
  inicializarSensores();
  inicializarRTC();
  iniciarEEPROM();
  inicializarDashboard();
  gsmSetup("igprs.claro.com.ar", "", "");

  // Primera lectura para no arrancar vacío
  leerDHT();
  leerLuz();
  leerGas();
  enviarInfoDispositivo();

  Serial.println(" Sistema listo.");
}

void loop() {
  // Interacción con menú
  if (digitalRead(BOTON_CONFIRMAR) == HIGH) {
    delay(200);  // debounce
    menuVisible = !menuVisible;

    if (menuVisible) {
      mostrarMenuPrincipal();
    } else {
      actualizarDashboard();
    }
  }

  // Lectura periódica de sensores
  if (millis() - ultimaLectura >= intervaloLectura) {
    ultimaLectura = millis();

    Serial.println("===== ACTUALIZANDO SENSORES =====");

    if (sensorTempAguaActivo) leerTemperaturaAgua();
    if (sensorAireActivo) leerDHT();
    if (sensorNivelAguaActivo) leerNivelAgua();
    if (sensorFlujoActivo) calcularFlujoAgua();
    if (sensorLuzActivo) leerLuz();
    if (sensorGasActivo) leerGas();
    if (sensorCorrienteActivo) leerCorriente();
    if (sensorPHActivo) leerPH();

    obtenerHora();
    enviarDatos();

    if (!menuVisible) {
      actualizarDashboard();
    }

    Serial.println("===== SENSORES ACTUALIZADOS =====");
    
  }
if (WiFi.status() == WL_CONNECTED && !mqttConectado) {
  static unsigned long ultimoIntentoMQTT = 0;
  unsigned long ahora = millis();
  
  // Intenta reconectar cada 5 segundos
  if (ahora - ultimoIntentoMQTT > 5000) {
    ultimoIntentoMQTT = ahora;
    Serial.println("Intentando reconectar MQTT...");
    getMqttClient().connect();
  }
 }

  delay(10);
}

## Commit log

2025-04-15 se añade extrutura 3D
    [Adaptador.stl, tapa.stl]
2025-04-16 agrego algunos archivos editables
    [Assem1.SLDASM, cup_holder_fer.SLDPRT, cup_holder_fer.STEP]
2025-04-17 se añade actualizacion del diseño 3d
    [Ensamblaje1.SLDASM, KY-015.SLDPRT, LCD_TFT_1.8_SPI_ST7735.SLDASM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]
2025-04-17 se actualizo base ldr y co2
    [base.SLDPRT]
2025-04-18 se actualizo base y se agrego sheild
    [Ensamblaje1.SLDASM, base.SLDPRT, nodencu base.SLDPRT]
2025-04-18 agrego sensores en formato STEP
    [3_8 inch push connect flow meter.step, DS18B20.stp, Light sensor LDR v1.step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]
2025-04-18 nuevos archivos 3d
    [3_8 inch push connect flow meter.SLDPRT, Light sensor LDR v1.SLDASM, LoRa_Module_RA-02_AiThinker.SLDPRT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]
2025-04-19 agrego en carpeta version 1_1 opcion para case y box de control
    [AHT25.SLDPRT, Ensamblaje1.SLDASM, KY-015.SLDPRT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]
2025-04-19 se ordenan archivos
    [3_8 inch push connect flow meter.SLDPRT, 3_8 inch push connect flow meter.step, Componente1.sldprt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]
2025-04-21 semordeno en carpeta
    [DS3231 RTC.SLDASM, Default.sldprt, INA219_I2C_IV_SENSOR_WITH_HEADER.SLDPRT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]
2025-04-21 Archivo tanque_bis para version 1_0 y agregados a version 1_1
    [20-Pin Header - Female - 2.54mm.SLDPRT, 20-Pin Header - Female - 2.54mm.step, LDR.SLDPRT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]
2025-04-21 Creacion de directorio general de frontend, y logica de renderizacion con django
2025-04-23 adelantando detalles
    [Rotary Encoder - KY-040.SLDPRT, chasis_perilla.SLDPRT, frente_control_box.SLDPRT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]
2025-04-23 Creadion de direcotiro de test unicario con logica unificada
2025-04-23 Se crea manual para uso del directorio
2025-04-23 Creacion (pacrial) de prueba SR04
2025-04-24 ultima act version 1_1
    [LoRa_Module_RA-02.SLDPRT, LoRa_Module_RA-02_AiThinker.SLDPRT, [3365] Water Flow Sensor YFS401 Flowmeter Water Flow Transmitter SunRobotics_in.STEP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]
2025-04-24 Correccion de manual
2025-04-24 Creacion de buzzer no limitante
    [main.cpp]
2025-04-25 se actualiza v1.0
    [HC-SR04.sldasm, Light sensor LDR v1.SLDPRT, MQ-7.SLDPRT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]
2025-04-25 agrego cambios a la base de la versio 1_0
    [Relay - 2 Channel - 2PH63091A - Montaj.SLDASM, base.SLDPRT, baseOpcionParaMasEspacio.SLDPRT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]
2025-04-26 Creacion prueba unitaria bomba, con clase, no bloqueante, y con definiciones por umbral, a demanda o con timer.
2025-04-26 Correccion de errores en espuesta de prueba bomba - Mejora gestion de envio/recibimiento msg via mqtt. Se corrige problema en cuelgue de conexion mqtt cuando wifi aun no da IP
    [bomba.cpp, main.cpp, mqtt_async.cpp]
2025-04-27 Creacion gestion modulo GSM. No bloqueando, y encapsulado. Se busca redirigir para manejo con flag
2025-04-27 Correcciones en compilacion | Listo para compilar y subir para testear modulo GSM
2025-05-01 cambio de pines
2025-05-02 Carga y actualizacion de documentos en base a la incorporacion de gsm
2025-05-03 modificacion en orden de directorios hidropinia2
2025-05-03 libreria lvgd - Problemas en complilacion
    [main.cpp]
2025-05-03 No se configuio conf correctament el lv_conf.h | Contiunan errores al llamar elemtnos | Se mejora la presentacion de .ini asi como de main
    [gsm_async.cpp, main.cpp, mqtt_async.cpp]
2025-05-05 Creaccion de gestion de errores (parcial) y documento catalogo de errores.
    [main.cpp]
2025-05-05 muestra lectura en la pantalla
2025-05-06 Correcciones varias, creacion del modulo de errores .h y .cpp para gestion de errores y logs mediante macro.
    [comunicacion.cpp, control.cpp, control.h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]
2025-05-06 Correccion de formato de envio de json en mqtt
2025-05-06 Correccion en funcion de GSM, mal escrita (init)
2025-05-07 API para gestion de datos del dispositivo
2025-05-08 correccion de carepta equivocada dentro del directorio
2025-05-08 Propuesta de base de datos
2025-05-12 Actualizacion Docker Basse de datos, y definicion de estrcutrua de mensaje
2025-05-19 Actualizacion de API y bases de datos
    Se carga el formato actualizado de la api/mqtt listenner + creacion y gestion de bases de datos. Todo listo para orquestar via docker en un unico docker compose.
    Para ejecutar en PC parase sobre el directorio /backend y escribir docker compose up --build
2025-05-23 Creacion de proxy + DDNS
    Se crea un DDNS gratuito via DUCK
    Se crea nginx a forma de proxy para despliegue de la aplicacion e ingresos remotos
    Se corrigen varias definiciones que generaban error en ejecuciones finales.
2025-06-13 se añadio la clase WebServerWifi para la configuración de Wi-Fi y la configuración de MQTT. Implementar la gestión de la conexión Wi-Fi con los modos AP (Punto de Acceso) y STA (Estación). Crear un f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
